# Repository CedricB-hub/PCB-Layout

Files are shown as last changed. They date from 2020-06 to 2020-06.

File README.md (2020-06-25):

# PCB-Layout

New Github repository to host a project sample

Licence Attribution-ShareAlike 3.0 Unported: https://creativecommons.org/licenses/by-sa/3.0/legalcode

The cover page, the block diagram, the schematics design notes and the pcb manufacturing notes were taken from the original design. The schematics library, pcb library, schematics, pcb design and release documentation were made according to what is shown in the course "Learn to design your own boards". (I wanted to repeat the pcb design steps shown by a professional from start to finish to learn pcb design best practices and better estimate the time it takes to develop a pcb with all the documentation for manufacturing)

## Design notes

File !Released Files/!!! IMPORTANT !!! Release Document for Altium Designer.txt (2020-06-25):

Follow this procedure before releasing files. Confirm every action with your initials and date.
IF ANY CHANGES NEEDS TO BE DONE, START THE PROCEDURE FROM BEGINNING!

The procedure needs to be executed in order as defined here. Start from number 1
--------------------------------------------------------------------------------

1) Right Click on the project -> Compile PCB project
I confirm, the project compiles with no errors: 
BC [22-06-2020]

2) Run Design -> Update PCB Document
I confirm, there are no differences between Schematic and PCB: 
BC [22-06-2020]

3) Impedance
I confirm, I have updated and check track width/gap to match required impedance (e.g 55 OHMs): 
NOT APPLICABLE  (two layers, low speed signals)

4) Run Tools -> Polygon Pours -> Rebuild All
I confirm, all polygons have been repoured: 
BC [22-06-2020]

5) Run Tools -> Design Rule Check -> Run Design Rule Check
I confirm, I have checked Design Rule Output File:
BC [22-06-2020]

6) Gerber check
I confirm, I have copied and visually checked gerber files placed in \PCB Manufacturing\Gerber Output\
BC [22-06-2020]

7) Other files
I confirm, I have copied and checked files placed in subdirectories:
BC [22-06-2020]

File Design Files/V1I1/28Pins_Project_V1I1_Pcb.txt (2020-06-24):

Board Information Report
Filename     : C:\Users\cedri\Desktop\FEDEVEL Academy\28 Pins\Design Files\V1I1\28Pins_Project_V1I1_Pcb.PcbDoc
Date         : 22/06/2020
Time         : 15:36:49
Time Elapsed : 00:00:01

General
    Board Size, 68.58mmx53.34mm
    Components on board, 106
count : 2

Routing Information
    Routing completion, 99,15%
    Connections, 236
    Connections routed, 234
    Connections remaining, 2
count : 4

Layer, Arcs, Pads, Vias, Tracks, Texts, Fills, Regions, ComponentBodies
    L1, 2, 221, 0, 913, 0, 0, 14, 0
    L2, 1, 0, 0, 94, 0, 0, 11, 0
    Mechanical 1, 0, 0, 0, 0, 0, 0, 0, 104
    Mechanical Drawing, 5, 0, 0, 149, 22, 0, 0, 0
    Manufacturing Notes, 0, 0, 0, 10, 32, 0, 0, 0
    License, 0, 0, 0, 0, 25, 0, 0, 0
    Board Outline, 0, 0, 0, 5, 0, 0, 0, 0
    ASM Top, 22, 0, 0, 391, 100, 0, 0, 0
    ASM Bot, 0, 0, 0, 0, 0, 0, 0, 0
    Multi-Layer, 0, 102, 105, 0, 0, 0, 1, 0
    Top Paste, 0, 0, 0, 0, 0, 0, 0, 0
    Top Overlay, 3, 0, 0, 423, 235, 0, 0, 0
    Top Solder, 0, 0, 0, 0, 0, 0, 0, 0
    Bottom Solder, 0, 0, 0, 0, 0, 0, 0, 0
    Bottom Overlay, 0, 0, 0, 0, 36, 0, 0, 0
    Bottom Paste, 0, 0, 0, 0, 0, 0, 0, 0
    Drill Guide, 0, 0, 0, 0, 0, 0, 0, 0
    Keep-Out Layer, 0, 0, 0, 0, 0, 0, 0, 0
    Drill Drawing, 0, 0, 0, 0, 0, 0, 0, 0
count : 19

Drill Pairs, Vias
    L1 - L2, 105
count : 1

Layer, Sq.In., Sq.MM., Percent of layer
    L1, 2,041, 1316,752, 36%
    L2, 3,972, 2562,467, 70%
count : 2

Non-Plated Hole Size, Pads, Vias
    3.2mm, 1, 0
count : 1

Plated Hole Size, Pads, Vias
    0mm, 221, 0
    0.3mm, 0, 105
    1mm, 8, 0
    1.1mm, 86, 0
    1.5mm, 2, 0
    3.2mm, 3, 0
count : 6

Non-Plated Slot Size / Length, Pads
count : 0

Plated Slot Size / Length, Pads
    19.685mil / 47.244mil, 2
count : 1

Non-Plated Square Hole Size, Pads
count : 0

Plated Square Hole Size, Pads
count : 0

Top Layer Annular Ring Size, Count
    0mm, 1
    0.3mm, 105
    0.6mm, 16
    0.9mm, 8
    0.9mm, 70
    1.5mm, 2
    2.5mm, 2
    4.2mm, 3
count : 8

Mid Layer Annular Ring Size, Count
    0mm, 1
    0.3mm, 105
    0.6mm, 16
    0.9mm, 8
    0.9mm, 70
    1.1mm, 1
    1.5mm, 1
    2.5mm, 2
    4.2mm, 3
count : 9

Bottom Layer Annular Ring Size, Count
    0mm, 1
    0.3mm, 105
    0.6mm, 16
    0.9mm, 8
    0.9mm, 70
    1.1mm, 1
    1.5mm, 1
    2.5mm, 2
    4.2mm, 3
count : 9

Pad Solder Mask, Count
    0.05mm, 5
    0.06mm, 32
    0.1mm, 282
    1.016mm, 4
count : 4

Pad Paste Mask, Count
    -1.016mm, 4
    0mm, 319
count : 2

Pad Pwr/Gnd Expansion, Count
    0.508mm, 323
count : 1

Pad Relief Conductor Width, Count
    0.254mm, 323
count : 1

Pad Relief Air Gap, Count
    0.254mm, 323
count : 1

Pad Relief Entries, Count
    4, 323
count : 1

Via Solder Mask, Count
    0.1mm, 85
    0.1016mm, 20
count : 2

Via Pwr/Gnd Expansion, Count
    0.508mm, 105
count : 1

Track Width, Count
    0.2mm, 907
    0.254mm, 154
    0.3mm, 619
    0.4mm, 14
    0.6mm, 204
    0.8mm, 61
    1mm, 26
count : 7

Arc Line Width, Count
    0.2mm, 4
    0.254mm, 7
    0.3mm, 3
    0.45mm, 1
    0.5mm, 3
    0.508mm, 7
    0.635mm, 3
    1.016mm, 5
count : 8

Arc Radius, Count
    0.1mm, 9
    0.2mm, 1
    0.2236mm, 2
    0.25mm, 1
    0.254mm, 10
    0.635mm, 1
    1.1833mm, 1
    1.6mm, 5
    1.8448mm, 1
    3.7mm, 1
    4.05mm, 1
count : 11

Arc Degrees, Count
    8, 1
    13, 2
    149, 1
    180, 1
    360, 28
count : 5

Text Height, Count
    0.5mm, 2
    0.6mm, 73
    0.8mm, 5
    1mm, 170
    1.016mm, 7
    1.27mm, 3
    1.524mm, 179
    1.8mm, 1
    2mm, 2
    3mm, 6
    4mm, 2
count : 11

Text Width, Count
    0.1mm, 76
    0.127mm, 4
    0.15mm, 1
    0.1524mm, 18
    0.2mm, 174
    0.25mm, 1
    0.254mm, 167
    0.3mm, 2
    0.5mm, 5
    0.8mm, 2
count : 10

Net Track Width, Count
    0.2mm, 61
    0.4mm, 10
count : 2

Net Via Size, Count
    0.6mm, 71
count : 1

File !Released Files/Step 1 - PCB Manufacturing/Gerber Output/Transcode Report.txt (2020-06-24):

   ---- Transcoding 'C:\Users\cedri\Desktop\FEDEVEL Academy\28 Pins\!Released Files\Step 1 - PCB Manufacturing\Gerber Output\28Pins_Project_V1I1_Pcb.GM2' ----   Mon Jun 22 15:15:35 2020

D88   --> D100
-----------------------------------------------------------------

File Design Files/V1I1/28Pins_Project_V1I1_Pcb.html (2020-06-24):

Altium customize

# Board Information Report

Date: | | 22/06/2020
Time: | | 15:36:49
Elapsed Time: | | 00:00:01
Filename: | | C:\Users\cedri\Desktop\FEDEVEL Academy\28 Pins\Design Files\V1I1\28Pins_Project_V1I1_Pcb.PcbDoc
Units: | | mmmils

## Contents

Contents

Board Specification

General

Routing

Routing Information

Layer Information

Layer Information

Drill Pairs

Copper Area

Copper Area

Board Holes

Non-Plated Hole Size

Plated Hole Size

Board Slots

Non-Plated Slot Size

Plated Slot Size

Board Square Holes

Non-Plated Square Hole Size

Plated Square Hole Size

Other

Top Layer Annular Ring Size

Mid Layer Annular Ring Size

Bottom Layer Annular Ring Size

Pad Solder Mask

Pad Paste Mask

Pad Pwr/Gnd Expansion

Pad Relief Conductor Width

Pad Relief Air Gap

Pad Relief Entries

Via Solder Mask

Via Pwr/Gnd Expansion

Track Width

Arc Line Width

Arc Radius

Arc Degrees

Text Height

Text Width

Net Track Width

Net Via Size

## Board Specification

General
Board Size | 68.58mm x 53.34mm
Components on board | 106

Back to top

## Routing

Routing Information
Routing completion | 99,15%
Connections | 236
Connections routed | 234
Connections remaining | 2

Back to top

## Layer Information

Layer | Arcs | Pads | Vias | Tracks | Texts | Fills | Regions | ComponentBodies
L1 | 2 | 221 | 0 | 913 | 0 | 0 | 14 | 0
L2 | 1 | 0 | 0 | 94 | 0 | 0 | 11 | 0
Mechanical 1 | 0 | 0 | 0 | 0 | 0 | 0 | 0 | 104
Mechanical Drawing | 5 | 0 | 0 | 149 | 22 | 0 | 0 | 0
Manufacturing Notes | 0 | 0 | 0 | 10 | 32 | 0 | 0 | 0
License | 0 | 0 | 0 | 0 | 25 | 0 | 0 | 0
Board Outline | 0 | 0 | 0 | 5 | 0 | 0 | 0 | 0
ASM Top | 22 | 0 | 0 | 391 | 100 | 0 | 0 | 0
ASM Bot | 0 | 0 | 0 | 0 | 0 | 0 | 0 | 0
Multi-Layer | 0 | 102 | 105 | 0 | 0 | 0 | 1 | 0
Top Paste | 0 | 0 | 0 | 0 | 0 | 0 | 0 | 0
Top Overlay | 3 | 0 | 0 | 423 | 235 | 0 | 0 | 0
Top Solder | 0 | 0 | 0 | 0 | 0 | 0 | 0 | 0
Bottom Solder | 0 | 0 | 0 | 0 | 0 | 0 | 0 | 0
Bottom Overlay | 0 | 0 | 0 | 0 | 36 | 0 | 0 | 0
Bottom Paste | 0 | 0 | 0 | 0 | 0 | 0 | 0 | 0
Drill Guide | 0 | 0 | 0 | 0 | 0 | 0 | 0 | 0
Keep-Out Layer | 0 | 0 | 0 | 0 | 0 | 0 | 0 | 0
Drill Drawing | 0 | 0 | 0 | 0 | 0 | 0 | 0 | 0
Total | 33 | 323 | 105 | 1985 | 450 | 0 | 26 | 104

Back to top

Drill Pairs | Vias
L1 - L2 | 105
Total | 105

Back to top

## Copper Area

Layer | Sq.In. | Sq.MM. | Percent of layer
L1 | 2,041 | 1316,752 | 36%
L2 | 3,972 | 2562,467 | 70%
Total | NaN | NaN

Back to top

## Board Holes

Non-Plated Hole Size | Pads | Vias
3.2mm | 1 | 0
Total | 1 | 0

Back to top

Plated Hole Size | Pads | Vias
0mm | 221 | 0
0.3mm | 0 | 105
1mm | 8 | 0
1.1mm | 86 | 0
1.5mm | 2 | 0
3.2mm | 3 | 0
Total | 320 | 105

Back to top

## Board Slots

Non-Plated Slot Size / Length | Pads
Total | 0

Back to top

Plated Slot Size / Length | Pads
19.685mil / 47.244mil | 2
Total | 2

Back to top

## Board Square Holes

Non-Plated Square Hole Size | Pads
Total | 0

Back to top

Plated Square Hole Size | Pads
Total | 0

Back to top

## Other

Top Layer Annular Ring Size | Count
0mm | 1
0.3mm | 105
0.6mm | 16
0.9mm | 8
0.9mm | 70
1.5mm | 2
2.5mm | 2
4.2mm | 3
Total | 207

Back to top

Mid Layer Annular Ring Size | Count
0mm | 1
0.3mm | 105
0.6mm | 16
0.9mm | 8
0.9mm | 70
1.1mm | 1
1.5mm | 1
2.5mm | 2
4.2mm | 3
Total | 207

Back to top

Bottom Layer Annular Ring Size | Count
0mm | 1
0.3mm | 105
0.6mm | 16
0.9mm | 8
0.9mm | 70
1.1mm | 1
1.5mm | 1
2.5mm | 2
4.2mm | 3
Total | 207

Back to top

Pad Solder Mask | Count
0.05mm | 5
0.06mm | 32
0.1mm | 282
1.016mm | 4
Total | 323

Back to top

Pad Paste Mask | Count
-1.016mm | 4
0mm | 319
Total | 323

Back to top

Pad Pwr/Gnd Expansion | Count
0.508mm | 323
Total | 323

Back to top

Pad Relief Conductor Width | Count
0.254mm | 323
Total | 323

Back to top

Pad Relief Air Gap | Count
0.254mm | 323
Total | 323

Back to top

Pad Relief Entries | Count
4 | 323
Total | 323

Back to top

Via Solder Mask | Count
0.1mm | 85
0.1016mm | 20
Total | 105

Back to top

Via Pwr/Gnd Expansion | Count
0.508mm | 105
Total | 105

Back to top

Track Width | Count
0.2mm | 907
0.254mm | 154
0.3mm | 619
0.4mm | 14
0.6mm | 204
0.8mm | 61
1mm | 26
Total | 1985

Back to top

Arc Line Width | Count
0.2mm | 4
0.254mm | 7
0.3mm | 3
0.45mm | 1
0.5mm | 3
0.508mm | 7
0.635mm | 3
1.016mm | 5
Total | 33

Back to top

Arc Radius | Count
0.1mm | 9
0.2mm | 1
0.2236mm | 2
0.25mm | 1
0.254mm | 10
0.635mm | 1
1.1833mm | 1
1.6mm | 5
1.8448mm | 1
3.7mm | 1
4.05mm | 1
Total | 33

Back to top

Arc Degrees | Count
8 | 1
13 | 2
149 | 1
180 | 1
360 | 28
Total | 33

Back to top

Text Height | Count
0.5mm | 2
0.6mm | 73
0.8mm | 5
1mm | 170
1.016mm | 7
1.27mm | 3
1.524mm | 179
1.8mm | 1
2mm | 2
3mm | 6
4mm | 2
Total | 450

Back to top

Text Width | Count
0.1mm | 76
0.127mm | 4
0.15mm | 1
0.1524mm | 18
0.2mm | 174
0.25mm | 1
0.254mm | 167
0.3mm | 2
0.5mm | 5
0.8mm | 2
Total | 450

Back to top

Net Track Width | Count
0.2mm | 61
0.4mm | 10
Total | 71

Back to top

Net Via Size | Count
0.6mm | 71
Total | 71

Back to top

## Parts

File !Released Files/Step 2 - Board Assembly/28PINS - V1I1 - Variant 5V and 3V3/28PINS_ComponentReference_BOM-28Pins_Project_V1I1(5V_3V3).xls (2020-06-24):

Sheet: Part List Report
 | Component reference list |  |  | DEV Board learning project
 |  | Source Data From: | 28Pins_Project_V1I1.PrjPcb |  | Contact: |  | Generated by:
 |  | Project: | 28Pins_Project_V1I1.PrjPcb
 |  | Variant: | 5V/3V3 |  |  |  | FEDEVEL
 | Report Date: | 22/06/2020 | 17:35 |  |  |  | http://www.fedevel.com
 | Print Date: | 2020-06-22 | 17:35:31
# | Designator | Comment | Description | Manufacturer 1 | Manufacturer Part Number 1 | Case/Package | Supplier 1 | Supplier Part Number 1
1 | C1 | 100u / 10V | Cap Aluminum 100uF 10V 20% (5 X 5.4mm) SMD 50mA 1000 hr 85°C T/R | Panasonic | EEE-1AA101WR | Radial | Digi-Key | PCE3867CT-ND
2 | C2 | 100u / 10V | Cap Aluminum 100uF 10V 20% (5 X 5.4mm) SMD 50mA 1000 hr 85°C T/R | Panasonic | EEE-1AA101WR | Radial | Digi-Key | PCE3867CT-ND
3 | C3 | 10u / 16V | TDK - C2012X5R1C106K085AC - SMD Multilayer Ceramic Capacitor, 10 µF, 16 V, 0805 [2012 Metric], ± 10%, X5R, C Series TDK | TDK | C2012X5R1C106K085AC | 805 | Digi-Key | 445-7644-1-ND
4 | C4 | 100n | TDK - C2012X7R1H104K085AA - SMD Multilayer Ceramic Capacitor, 0.1 µF, 50 V, 0805 [2012 Metric], ± 10%, X7R, C Series | TDK | C2012X7R1H104K085AA | 805 | Digi-Key | 445-7534-1-ND
5 | C5 | 100n | TDK - C2012X7R1H104K085AA - SMD Multilayer Ceramic Capacitor, 0.1 µF, 50 V, 0805 [2012 Metric], ± 10%, X7R, C Series | TDK | C2012X7R1H104K085AA | 805 | Digi-Key | 445-7534-1-ND
6 | C6 | 100n | TDK - C2012X7R1H104K085AA - SMD Multilayer Ceramic Capacitor, 0.1 µF, 50 V, 0805 [2012 Metric], ± 10%, X7R, C Series | TDK | C2012X7R1H104K085AA | 805 | Digi-Key | 445-7534-1-ND
7 | C7 | 1u / 25V | TDK - C2012X5R1E105K125AA - SMD Multilayer Ceramic Capacitor, 1 µF, 25 V, 0805 [2012 Metric], ± 10%, X5R, C Series | TDK | C2012X5R1E105K125AA | 805 | Digi-Key | 445-1419-1-ND
8 | C8 | 100n | TDK - C2012X7R1H104K085AA - SMD Multilayer Ceramic Capacitor, 0.1 µF, 50 V, 0805 [2012 Metric], ± 10%, X7R, C Series | TDK | C2012X7R1H104K085AA | 805 | Digi-Key | 445-7534-1-ND
9 | C9 | 18p | CAP CER 18PF 50V C0G/NP0 0805 | KEMET | C0805C180J5GACTU | 805 | Digi-Key | 399-1112-1-ND
10 | C10 | 18p | CAP CER 18PF 50V C0G/NP0 0805 | KEMET | C0805C180J5GACTU | 805 | Digi-Key | 399-1112-1-ND
11 | C11 | 100n | TDK - C2012X7R1H104K085AA - SMD Multilayer Ceramic Capacitor, 0.1 µF, 50 V, 0805 [2012 Metric], ± 10%, X7R, C Series | TDK | C2012X7R1H104K085AA | 805 | Digi-Key | 445-7534-1-ND
12 | C12 | 10u / 16V | TDK - C2012X5R1C106K085AC - SMD Multilayer Ceramic Capacitor, 10 µF, 16 V, 0805 [2012 Metric], ± 10%, X5R, C Series TDK | TDK | C2012X5R1C106K085AC | 805 | Digi-Key | 445-7644-1-ND
13 | C13 | 10u / 16V | TDK - C2012X5R1C106K085AC - SMD Multilayer Ceramic Capacitor, 10 µF, 16 V, 0805 [2012 Metric], ± 10%, X5R, C Series TDK | TDK | C2012X5R1C106K085AC | 805 | Digi-Key | 445-7644-1-ND
14 | C14 | 100n | TDK - C2012X7R1H104K085AA - SMD Multilayer Ceramic Capacitor, 0.1 µF, 50 V, 0805 [2012 Metric], ± 10%, X7R, C Series | TDK | C2012X7R1H104K085AA | 805 | Digi-Key | 445-7534-1-ND
15 | C15 | 100n | TDK - C2012X7R1H104K085AA - SMD Multilayer Ceramic Capacitor, 0.1 µF, 50 V, 0805 [2012 Metric], ± 10%, X7R, C Series | TDK | C2012X7R1H104K085AA | 805 | Digi-Key | 445-7534-1-ND
16 | C16 | 100n | TDK - C2012X7R1H104K085AA - SMD Multilayer Ceramic Capacitor, 0.1 µF, 50 V, 0805 [2012 Metric], ± 10%, X7R, C Series | TDK | C2012X7R1H104K085AA | 805 | Digi-Key | 445-7534-1-ND
17 | C17 | 100n | TDK - C2012X7R1H104K085AA - SMD Multilayer Ceramic Capacitor, 0.1 µF, 50 V, 0805 [2012 Metric], ± 10%, X7R, C Series | TDK | C2012X7R1H104K085AA | 805 | Digi-Key | 445-7534-1-ND
18 | C19 | 10u / 16V | TDK - C2012X5R1C106K085AC - SMD Multilayer Ceramic Capacitor, 10 µF, 16 V, 0805 [2012 Metric], ± 10%, X5R, C Series TDK | TDK | C2012X5R1C106K085AC | 805 | Digi-Key | 445-7644-1-ND
19 | C20 | 100n | TDK - C2012X7R1H104K085AA - SMD Multilayer Ceramic Capacitor, 0.1 µF, 50 V, 0805 [2012 Metric], ± 10%, X7R, C Series | TDK | C2012X7R1H104K085AA | 805 | Digi-Key | 445-7534-1-ND
20 | C21 | 10u / 16V | TDK - C2012X5R1C106K085AC - SMD Multilayer Ceramic Capacitor, 10 µF, 16 V, 0805 [2012 Metric], ± 10%, X5R, C Series TDK | TDK | C2012X5R1C106K085AC | 805 | Digi-Key | 445-7644-1-ND
21 | C22 | 10u / 16V | TDK - C2012X5R1C106K085AC - SMD Multilayer Ceramic Capacitor, 10 µF, 16 V, 0805 [2012 Metric], ± 10%, X5R, C Series TDK | TDK | C2012X5R1C106K085AC | 805 | Digi-Key | 445-7644-1-ND
22 | C23 | 100n | TDK - C2012X7R1H104K085AA - SMD Multilayer Ceramic Capacitor, 0.1 µF, 50 V, 0805 [2012 Metric], ± 10%, X7R, C Series | TDK | C2012X7R1H104K085AA | 805 | Digi-Key | 445-7534-1-ND
23 | C24 | 100n | TDK - C2012X7R1H104K085AA - SMD Multilayer Ceramic Capacitor, 0.1 µF, 50 V, 0805 [2012 Metric], ± 10%, X7R, C Series | TDK | C2012X7R1H104K085AA | 805 | Digi-Key | 445-7534-1-ND
24 | C25 | 18p | CAP CER 18PF 50V C0G/NP0 0805 | KEMET | C0805C180J5GACTU | 805 | Digi-Key | 399-1112-1-ND
25 | C26 | 100n | TDK - C2012X7R1H104K085AA - SMD Multilayer Ceramic Capacitor, 0.1 µF, 50 V, 0805 [2012 Metric], ± 10%, X7R, C Series | TDK | C2012X7R1H104K085AA | 805 | Digi-Key | 445-7534-1-ND
26 | C27 | 18p | CAP CER 18PF 50V C0G/NP0 0805 | KEMET | C0805C180J5GACTU | 805 | Digi-Key | 399-1112-1-ND
27 | C28 | 100n | TDK - C2012X7R1H104K085AA - SMD Multilayer Ceramic Capacitor, 0.1 µF, 50 V, 0805 [2012 Metric], ± 10%, X7R, C Series | TDK | C2012X7R1H104K085AA | 805 | Digi-Key | 445-7534-1-ND
28 | C29 | 100n | TDK - C2012X7R1H104K085AA - SMD Multilayer Ceramic Capacitor, 0.1 µF, 50 V, 0805 [2012 Metric], ± 10%, X7R, C Series | TDK | C2012X7R1H104K085AA | 805 | Digi-Key | 445-7534-1-ND
29 | C30 | 100n | TDK - C2012X7R1H104K085AA - SMD Multilayer Ceramic Capacitor, 0.1 µF, 50 V, 0805 [2012 Metric], ± 10%, X7R, C Series | TDK | C2012X7R1H104K085AA | 805 | Digi-Key | 445-7534-1-ND
30 | C31 | 100n | TDK - C2012X7R1H104K085AA - SMD Multilayer Ceramic Capacitor, 0.1 µF, 50 V, 0805 [2012 Metric], ± 10%, X7R, C Series | TDK | C2012X7R1H104K085AA | 805 | Digi-Key | 445-7534-1-ND
31 | C32 | 100n | TDK - C2012X7R1H104K085AA - SMD Multilayer Ceramic Capacitor, 0.1 µF, 50 V, 0805 [2012 Metric], ± 10%, X7R, C Series | TDK | C2012X7R1H104K085AA | 805 | Digi-Key | 445-7534-1-ND
32 | C33 | 100n | TDK - C2012X7R1H104K085AA - SMD Multilayer Ceramic Capacitor, 0.1 µF, 50 V, 0805 [2012 Metric], ± 10%, X7R, C Series | TDK | C2012X7R1H104K085AA | 805 | Digi-Key | 445-7534-1-ND
33 | C34 | 10u / 16V | TDK - C2012X5R1C106K085AC - SMD Multilayer Ceramic Capacitor, 10 µF, 16 V, 0805 [2012 Metric], ± 10%, X5R, C Series TDK | TDK | C2012X5R1C106K085AC | 805 | Digi-Key | 445-7644-1-ND
34 | D1 | Green | LED Uni-Color Green 572nm 2-Pin Chip 0603(1608Metric) T/R | Osram Opto | LGL29K-G2J1-24-Z | 603 | Digi-Key | 475-2709-1-ND
35 | D2 | Green | LED Uni-Color Green 572nm 2-Pin Chip 0603(1608Metric) T/R | Osram Opto | LGL29K-G2J1-24-Z | 603 | Digi-Key | 475-2709-1-ND
36 | D3 | Orange | OSRAM - LO L29K-H2K1-24-Z - SMARTLED 0603 ORANGE | Osram Opto | LOL29K-H2K1-24-Z | 603 | Digi-Key | 475-2740-1-ND
37 | D4 | Orange | OSRAM - LO L29K-H2K1-24-Z - SMARTLED 0603 ORANGE | Osram Opto | LOL29K-H2K1-24-Z | 603 | Digi-Key | 475-2740-1-ND
38 | D5 | BAT54HT1G | Small Signal Schottky Diode, Single, 30 V, 200 mA, 800 mV, 600 mA, 150 C ;RoHS Compliant: Yes | ON Semiconductor / Fairchild | BAT54HT1G |  | Digi-Key | BAT54HT1GOSCT-ND
39 | D6 | BAT54HT1G | Small Signal Schottky Diode, Single, 30 V, 200 mA, 800 mV, 600 mA, 150 C ;RoHS Compliant: Yes | ON Semiconductor / Fairchild | BAT54HT1G |  | Digi-Key | BAT54HT1GOSCT-ND
40 | FB1 | MPZ2012S601AT000 | FERRITE BEAD 600 OHM 0805 1LN | TDK | MPZ2012S601AT000 | 805 | Digi-Key | 445-2206-1-ND
41 | FB2 | MPZ2012S601AT000 | FERRITE BEAD 600 OHM 0805 1LN | TDK | MPZ2012S601AT000 | 805 | Digi-Key | 445-2206-1-ND
42 | FB3 | MPZ2012S601AT000 | FERRITE BEAD 600 OHM 0805 1LN | TDK | MPZ2012S601AT000 | 805 | Digi-Key | 445-2206-1-ND
43 | J1 | HDR FEMALE 1x8 2.54 | 2.54mm (0.1") Pitch SIL Vertical PC Tail Socket Assembly, selective gold + tin, 8 contacts | Harwin | M20-7820842 | SIL | Digi-Key | 952-1823-ND
44 | J2 | HDR Female 1x6 2.54 | 06-WAY SIL VERT SOCKET L/FREE | Harwin | M20-7820646 | SIL | Digi-Key | 952-1809-ND
45 | J3 | HDR FEMALE 1x8 2.54 | 2.54mm (0.1") Pitch SIL Vertical PC Tail Socket Assembly, selective gold + tin, 8 contacts | Harwin | M20-7820842 | SIL | Digi-Key | 952-1823-ND
46 | J4 | HDR Female 1x10 2.54 | HARWIN - M20-7821046 - Board-To-Board Connector, M20 Series, Through Hole, Receptacle, 10, 2.54 mm, Tin Plated Contacts | Harwin | M20-7821046 | SIL | Digi-Key | 952-1847-ND
47 | J5 | HDR 2x3 2.54 | CONN HEADER 6POS .100 STR 30AU | Amphenol ICC / FCI | 67997-106HLF |  | Digi-Key | 609-3393-ND
48 | J6 | HDR 2x3 2.54 | CONN HEADER 6POS .100 STR 30AU | Amphenol ICC / FCI | 67997-106HLF |  | Digi-Key | 609-3393-ND
49 | J7 | 10118193-0001LF | CONN USB MICRO B RECPT SMT R/A | AMPHENOL ICC (FCI) | 10118193-0001LF |  | Digi-Key | 609-4616-1-ND
50 | JP1 | HDR 1x3 | Conn Unshrouded Header HDR 3 POS 2.54mm Solder ST Thru-Hole Bulk | Amphenol ICC | 68000-103HLF |  | Digi-Key | 609-3461-ND
51 | JP3 | HDR 1x4 | CONN HEADER VERT 4POS 2.54MM | Amphenol FCI | 68001-204HLF |  | Digi-Key | 609-3402-ND
52 | JP4 | HDR 1x3 | Conn Unshrouded Header HDR 3 POS 2.54mm Solder ST Thru-Hole Bulk | Amphenol ICC | 68000-103HLF |  | Digi-Key | 609-3461-ND
53 | L1 | 2u2 / 2A | FIXED IND 2.2UH 2A 80 MOHM SMD | KEMET | L1210R2R2MDWIT | 1210 | Digi-Key | 399-9598-1-ND
54 | LINK1 | LINK | CONN JUMPER SHORTING .100" GOLD | Sullins | QPC02SXGN-RC | 100 | Digi-Key | S9337-ND
55 | LINK2 | LINK | CONN JUMPER SHORTING .100" GOLD | Sullins | QPC02SXGN-RC | 100 | Digi-Key | S9337-ND
56 | LINK3 | LINK | CONN JUMPER SHORTING .100" GOLD | Sullins | QPC02SXGN-RC | 100 | Digi-Key | S9337-ND
57 | R1 | 100K | YAGEO RC0805FR-07100KL RES, THICK FILM, 100K, 1%, 0.125W, 0805, REEL | Yageo | RC0805FR-07100KL | 805 | Digi-Key | 311-100KCRCT-ND
58 | R2 | 560R | Surface Mount Thick Film Resistor, RC Series, 560 ohm, 125 mW, - 1%, 150 V, 0805 [2012 Metric] | Yageo | RC0805FR-07560RL | 805 | Digi-Key | 311-560CRCT-ND
59 | R3 | 560R | Surface Mount Thick Film Resistor, RC Series, 560 ohm, 125 mW, - 1%, 150 V, 0805 [2012 Metric] | Yageo | RC0805FR-07560RL | 805 | Digi-Key | 311-560CRCT-ND
60 | R4 | 10K | RES SMD 10K OHM 1% 1/8W 0805 | Yageo | RC0805FR-0710KL | 805 | Digi-Key | 311-10.0KCRCT-ND
61 | R5 | 22R | RES SMD 22 OHM 1% 1/8W 0805 | Yageo | RC0805FR-0722RL | 805 | Digi-Key | 311-22.0CRCT-ND
62 | R6 | 22R | RES SMD 22 OHM 1% 1/8W 0805 | Yageo | RC0805FR-0722RL | 805 | Digi-Key | 311-22.0CRCT-ND
63 | R7 | 22R | RES SMD 22 OHM 1% 1/8W 0805 | Yageo | RC0805FR-0722RL | 805 | Digi-Key | 311-22.0CRCT-ND
64 | R8 | 0R | Surface Mount Thick Film Resistor, RC Series, 125 mW, - 5%, 150 V, 0805 [2012 Metric] | Yageo | RC0805JR-070RL | 805 | Digi-Key | 311-0.0ARCT-ND
65 | R9 | 1M | RES SMD 1M OHM 1% 1/8W 0805 | Yageo | RC0805FR-071ML | 805 | Digi-Key | 311-1.00MCRCT-ND
66 | R10 | 1K | RESISTOR, 0805 1K 1%, FULL REEL; Product Range:YAGEO - RC Series; Resistance:1kohm; Power Rating:125mW; Resistance Tolerance:± 1%; Resistor Case Style:0805 [2012 Metric]; Resistor Element Material:Thick Film; Temperature Coefficient:± 250ppm/°C; Voltage Rating:150V; Packaging:Tape & Reel; MSL:-; SVHC:No SVHC (16-Dec-2013); External Depth:0.55mm; External Length / Height:2mm; External Width:1.25mm; No. of Pins:2; Operating Temperature Max:155°C; Operating Temperature Min:-55°C; Operating Temperature Range:-55°C to +155°C; Reel Quantity:5000; Resistor Mounting:SMD; Series:RC12H; Temperature Coef | Yageo | RC0805FR-071KL | 805 | Digi-Key | 311-1.00KCRCT-ND
67 | R11 | 1K | RESISTOR, 0805 1K 1%, FULL REEL; Product Range:YAGEO - RC Series; Resistance:1kohm; Power Rating:125mW; Resistance Tolerance:± 1%; Resistor Case Style:0805 [2012 Metric]; Resistor Element Material:Thick Film; Temperature Coefficient:± 250ppm/°C; Voltage Rating:150V; Packaging:Tape & Reel; MSL:-; SVHC:No SVHC (16-Dec-2013); External Depth:0.55mm; External Length / Height:2mm; External Width:1.25mm; No. of Pins:2; Operating Temperature Max:155°C; Operating Temperature Min:-55°C; Operating Temperature Range:-55°C to +155°C; Reel Quantity:5000; Resistor Mounting:SMD; Series:RC12H; Temperature Coef | Yageo | RC0805FR-071KL | 805 | Digi-Key | 311-1.00KCRCT-ND
68 | R12 | 1K | RESISTOR, 0805 1K 1%, FULL REEL; Product Range:YAGEO - RC Series; Resistance:1kohm; Power Rating:125mW; Resistance Tolerance:± 1%; Resistor Case Style:0805 [2012 Metric]; Resistor Element Material:Thick Film; Temperature Coefficient:± 250ppm/°C; Voltage Rating:150V; Packaging:Tape & Reel; MSL:-; SVHC:No SVHC (16-Dec-2013); External Depth:0.55mm; External Length / Height:2mm; External Width:1.25mm; No. of Pins:2; Operating Temperature Max:155°C; Operating Temperature Min:-55°C; Operating Temperature Range:-55°C to +155°C; Reel Quantity:5000; Resistor Mounting:SMD; Series:RC12H; Temperature Coef | Yageo | RC0805FR-071KL | 805 | Digi-Key | 311-1.00KCRCT-ND
69 | R13 | 22R | RES SMD 22 OHM 1% 1/8W 0805 | Yageo | RC0805FR-0722RL | 805 | Digi-Key | 311-22.0CRCT-ND
70 | R14 | 10K | RES SMD 10K OHM 1% 1/8W 0805 | Yageo | RC0805FR-0710KL | 805 | Digi-Key | 311-10.0KCRCT-ND
71 | R15 | 560R | Surface Mount Thick Film Resistor, RC Series, 560 ohm, 125 mW, - 1%, 150 V, 0805 [2012 Metric] | Yageo | RC0805FR-07560RL | 805 | Digi-Key | 311-560CRCT-ND
72 | R16 | 1M | RES SMD 1M OHM 1% 1/8W 0805 | Yageo | RC0805FR-071ML | 805 | Digi-Key | 311-1.00MCRCT-ND
73 | R17 | 560R | Surface Mount Thick Film Resistor, RC Series, 560 ohm, 125 mW, - 1%, 150 V, 0805 [2012 Metric] | Yageo | RC0805FR-07560RL | 805 | Digi-Key | 311-560CRCT-ND
74 | R18 | 10K | RES SMD 10K OHM 1% 1/8W 0805 | Yageo | RC0805FR-0710KL | 805 | Digi-Key | 311-10.0KCRCT-ND
75 | R19 | 10K | RES SMD 10K OHM 1% 1/8W 0805 | Yageo | RC0805FR-0710KL | 805 | Digi-Key | 311-10.0KCRCT-ND
76 | R20 | 10K | RES SMD 10K OHM 1% 1/8W 0805 | Yageo | RC0805FR-0710KL | 805 | Digi-Key | 311-10.0KCRCT-ND
77 | R21 | 10K | RES SMD 10K OHM 1% 1/8W 0805 | Yageo | RC0805FR-0710KL | 805 | Digi-Key | 311-10.0KCRCT-ND
78 | R22 | 560R | Surface Mount Thick Film Resistor, RC Series, 560 ohm, 125 mW, - 1%, 150 V, 0805 [2012 Metric] | Yageo | RC0805FR-07560RL | 805 | Digi-Key | 311-560CRCT-ND
79 | R23 | 22R | RES SMD 22 OHM 1% 1/8W 0805 | Yageo | RC0805FR-0722RL | 805 | Digi-Key | 311-22.0CRCT-ND
80 | R24 | 22R | RES SMD 22 OHM 1% 1/8W 0805 | Yageo | RC0805FR-0722RL | 805 | Digi-Key | 311-22.0CRCT-ND
81 | R25 | 22R | RES SMD 22 OHM 1% 1/8W 0805 | Yageo | RC0805FR-0722RL | 805 | Digi-Key | 311-22.0CRCT-ND
82 | SCKT FOR U1 | 28-DIP Socket | CONN IC DIP SOCKET 28POS TIN | 3M | 7010501790 |  | Digi-Key | 3M5480-ND
83 | SW1 | 1825910-6 | SWITCH TACTILE SPST-NO 0.05A 24V | TE Connectivity | FSM4JH |  | Digi-Key | 450-1650-ND
84 | SW2 | 1825910-6 | SWITCH TACTILE SPST-NO 0.05A 24V | TE Connectivity | FSM4JH |  | Digi-Key | 450-1650-ND
85 | U1 | ATMEGA328P-PU | ATMEGA328P-PU; 8 bit Microcontroller AVR 20MHz 1; 32kb Flash; 2kb RAM; I2C SPI 2 | Microchip / Atmel | ATMEGA328P-PU |  | Digi-Key | ATMEGA328P-PU-ND
86 | U2 | ATMEGA16U2-AU | ATmega Series 16 KB Flash 512 B RAM 16 MHz 8-Bit Microcontroller - TQFP-32 | Microchip / Atmel | ATMEGA16U2-AU | TQFP | Digi-Key | ATMEGA16U2-AU-ND
87 | U3 | TL1963A-33DCQR | IC REG LINEAR 3.3V 1.5A SOT223-6 | Texas Instruments | TL1963A-33DCQR | SOT-223 | Digi-Key | 296-24534-1-ND
88 | U4 | SN74AHC1G09DBVR | TEXAS INSTRUMENTS - SN74AHC1G09DBVR - AND Gate, 74AHC1G09, 2 Input, 2 V to 5.5 V, SOT-23-5 | Texas Instruments | SN74AHC1G09DBVR | SOT-23 | Digi-Key | 296-29202-1-ND
89 | U5 | SN74AHC1G09DBVR | TEXAS INSTRUMENTS - SN74AHC1G09DBVR - AND Gate, 74AHC1G09, 2 Input, 2 V to 5.5 V, SOT-23-5 | Texas Instruments | SN74AHC1G09DBVR | SOT-23 | Digi-Key | 296-29202-1-ND
90 | U6 | SN74AHC1G09DBVR | TEXAS INSTRUMENTS - SN74AHC1G09DBVR - AND Gate, 74AHC1G09, 2 Input, 2 V to 5.5 V, SOT-23-5 | Texas Instruments | SN74AHC1G09DBVR | SOT-23 | Digi-Key | 296-29202-1-ND
91 | U7 | SN74AHC1G09DBVR | TEXAS INSTRUMENTS - SN74AHC1G09DBVR - AND Gate, 74AHC1G09, 2 Input, 2 V to 5.5 V, SOT-23-5 | Texas Instruments | SN74AHC1G09DBVR | SOT-23 | Digi-Key | 296-29202-1-ND
92 | Y1 | ABM7-10.000MHZ-D2Y-T | CRYSTAL 10.0000MHZ 18PF SMD | Abracon | ABM7-10.000MHZ-D2Y-T | SMD/SMT | Digi-Key | 535-9833-1-ND
93 | Y2 | ABM7-8.000MHZ-D2Y-T | ABRACON - ABM7-8.000MHZ-D2Y-T - Crystal, Miniature, 8 MHz, SMD, 6mm x 3.5mm, 30 ppm, 18 pF, 20 ppm, ABM7 Series | Abracon | ABM7-8.000MHZ-D2Y-T | CSMD | Digi-Key | 535-9831-1-ND
94 | Z1 | CG0603MLC-05E | VARISTOR 0603 | Bourns | CG0603MLC-05E | 603 | Digi-Key | CG0603MLC-05ECT-ND
95 | Z2 | CG0603MLC-05E | VARISTOR 0603 | Bourns | CG0603MLC-05E | 603 | Digi-Key | CG0603MLC-05ECT-ND
Approved |  |  |  | Notes

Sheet: Project Information
Project Full Path | C:\Users\cedri\Desktop\FEDEVEL Academy\28 Pins\Design Files\V1I1\28Pins_Project_V1I1.PrjPcb
Project Filename | 28Pins_Project_V1I1.PrjPcb
Variant Name | 5V/3V3
Data-Source Filename | 28Pins_Project_V1I1.PrjPcb
Data-Source Full Path | C:\Users\cedri\Desktop\FEDEVEL Academy\28 Pins\Design Files\V1I1\28Pins_Project_V1I1.PrjPcb
Title | 28Pins_Project_V1I1.PrjPcb
Total Quantity | 95
Report Time | 17:35
Report Date | 22/06/2020
Report Date & Tine | 22/06/2020 17:35
Output Name | 28PINS_ComponentReference_BOM
Output Type | BOM_PartType
Output Generator Name | BOM
Output Generator Description | Bill of Materials

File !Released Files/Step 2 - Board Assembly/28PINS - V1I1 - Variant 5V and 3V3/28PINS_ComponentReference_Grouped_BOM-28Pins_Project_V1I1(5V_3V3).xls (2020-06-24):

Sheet: Part List Report
 | Component reference list (grouped) |  |  |  | DEV Board learning project
 | Source Data From: |  | 28Pins_Project_V1I1.PrjPcb |  |  | Contact: |  | Generated by:
 | Project: |  | 28Pins_Project_V1I1.PrjPcb
 | Variant: |  | 5V/3V3 |  |  |  |  | FEDEVEL
 | Report Date: |  | 22/06/2020 | 17:46 |  |  |  | http://www.fedevel.com
 | Print Date: |  | 2020-06-22 | 17:46:30
# | Designator | Quantity | Comment | Description | Manufacturer 1 | Manufacturer Part Number 1 | Case/Package | Supplier 1 | Supplier Part Number 1
1 | C1, C2 | 2 | 100u / 10V | Cap Aluminum 100uF 10V 20% (5 X 5.4mm) SMD 50mA 1000 hr 85°C T/R | Panasonic | EEE-1AA101WR | Radial | Digi-Key | PCE3867CT-ND
2 | C3, C12, C13, C19, C21, C22, C34 | 7 | 10u / 16V | TDK - C2012X5R1C106K085AC - SMD Multilayer Ceramic Capacitor, 10 µF, 16 V, 0805 [2012 Metric], ± 10%, X5R, C Series TDK | TDK | C2012X5R1C106K085AC | 805 | Digi-Key | 445-7644-1-ND
3 | C4, C5, C6, C8, C11, C14, C15, C16, C17, C20, C23, C24, C26, C28, C29, C30, C31, C32, C33 | 19 | 100n | TDK - C2012X7R1H104K085AA - SMD Multilayer Ceramic Capacitor, 0.1 µF, 50 V, 0805 [2012 Metric], ± 10%, X7R, C Series | TDK | C2012X7R1H104K085AA | 805 | Digi-Key | 445-7534-1-ND
4 | C7 | 1 | 1u / 25V | TDK - C2012X5R1E105K125AA - SMD Multilayer Ceramic Capacitor, 1 µF, 25 V, 0805 [2012 Metric], ± 10%, X5R, C Series | TDK | C2012X5R1E105K125AA | 805 | Digi-Key | 445-1419-1-ND
5 | C9, C10, C25, C27 | 4 | 18p | CAP CER 18PF 50V C0G/NP0 0805 | KEMET | C0805C180J5GACTU | 805 | Digi-Key | 399-1112-1-ND
6 | D1, D2 | 2 | Green | LED Uni-Color Green 572nm 2-Pin Chip 0603(1608Metric) T/R | Osram Opto | LGL29K-G2J1-24-Z | 603 | Digi-Key | 475-2709-1-ND
7 | D3, D4 | 2 | Orange | OSRAM - LO L29K-H2K1-24-Z - SMARTLED 0603 ORANGE | Osram Opto | LOL29K-H2K1-24-Z | 603 | Digi-Key | 475-2740-1-ND
8 | D5, D6 | 2 | BAT54HT1G | Small Signal Schottky Diode, Single, 30 V, 200 mA, 800 mV, 600 mA, 150 C ;RoHS Compliant: Yes | ON Semiconductor / Fairchild | BAT54HT1G |  | Digi-Key | BAT54HT1GOSCT-ND
9 | FB1, FB2, FB3 | 3 | MPZ2012S601AT000 | FERRITE BEAD 600 OHM 0805 1LN | TDK | MPZ2012S601AT000 | 805 | Digi-Key | 445-2206-1-ND
10 | J1, J3 | 2 | HDR FEMALE 1x8 2.54 | 2.54mm (0.1") Pitch SIL Vertical PC Tail Socket Assembly, selective gold + tin, 8 contacts | Harwin | M20-7820842 | SIL | Digi-Key | 952-1823-ND
11 | J2 | 1 | HDR Female 1x6 2.54 | 06-WAY SIL VERT SOCKET L/FREE | Harwin | M20-7820646 | SIL | Digi-Key | 952-1809-ND
12 | J4 | 1 | HDR Female 1x10 2.54 | HARWIN - M20-7821046 - Board-To-Board Connector, M20 Series, Through Hole, Receptacle, 10, 2.54 mm, Tin Plated Contacts | Harwin | M20-7821046 | SIL | Digi-Key | 952-1847-ND
13 | J5, J6 | 2 | HDR 2x3 2.54 | CONN HEADER 6POS .100 STR 30AU | Amphenol ICC / FCI | 67997-106HLF |  | Digi-Key | 609-3393-ND
14 | J7 | 1 | 10118193-0001LF | CONN USB MICRO B RECPT SMT R/A | AMPHENOL ICC (FCI) | 10118193-0001LF |  | Digi-Key | 609-4616-1-ND
15 | JP1, JP4 | 2 | HDR 1x3 | Conn Unshrouded Header HDR 3 POS 2.54mm Solder ST Thru-Hole Bulk | Amphenol ICC | 68000-103HLF |  | Digi-Key | 609-3461-ND
16 | JP3 | 1 | HDR 1x4 | CONN HEADER VERT 4POS 2.54MM | Amphenol FCI | 68001-204HLF |  | Digi-Key | 609-3402-ND
17 | L1 | 1 | 2u2 / 2A | FIXED IND 2.2UH 2A 80 MOHM SMD | KEMET | L1210R2R2MDWIT | 1210 | Digi-Key | 399-9598-1-ND
18 | LINK1, LINK2, LINK3 | 3 | LINK | CONN JUMPER SHORTING .100" GOLD | Sullins | QPC02SXGN-RC | 100 | Digi-Key | S9337-ND
19 | R1 | 1 | 100K | YAGEO RC0805FR-07100KL RES, THICK FILM, 100K, 1%, 0.125W, 0805, REEL | Yageo | RC0805FR-07100KL | 805 | Digi-Key | 311-100KCRCT-ND
20 | R2, R3, R15, R17, R22 | 5 | 560R | Surface Mount Thick Film Resistor, RC Series, 560 ohm, 125 mW, - 1%, 150 V, 0805 [2012 Metric] | Yageo | RC0805FR-07560RL | 805 | Digi-Key | 311-560CRCT-ND
21 | R4, R14, R18, R19, R20, R21 | 6 | 10K | RES SMD 10K OHM 1% 1/8W 0805 | Yageo | RC0805FR-0710KL | 805 | Digi-Key | 311-10.0KCRCT-ND
22 | R5, R6, R7, R13, R23, R24, R25 | 7 | 22R | RES SMD 22 OHM 1% 1/8W 0805 | Yageo | RC0805FR-0722RL | 805 | Digi-Key | 311-22.0CRCT-ND
23 | R8 | 1 | 0R | Surface Mount Thick Film Resistor, RC Series, 125 mW, - 5%, 150 V, 0805 [2012 Metric] | Yageo | RC0805JR-070RL | 805 | Digi-Key | 311-0.0ARCT-ND
24 | R9, R16 | 2 | 1M | RES SMD 1M OHM 1% 1/8W 0805 | Yageo | RC0805FR-071ML | 805 | Digi-Key | 311-1.00MCRCT-ND
25 | R10, R11, R12 | 3 | 1K | RESISTOR, 0805 1K 1%, FULL REEL; Product Range:YAGEO - RC Series; Resistance:1kohm; Power Rating:125mW; Resistance Tolerance:± 1%; Resistor Case Style:0805 [2012 Metric]; Resistor Element Material:Thick Film; Temperature Coefficient:± 250ppm/°C; Voltage Rating:150V; Packaging:Tape & Reel; MSL:-; SVHC:No SVHC (16-Dec-2013); External Depth:0.55mm; External Length / Height:2mm; External Width:1.25mm; No. of Pins:2; Operating Temperature Max:155°C; Operating Temperature Min:-55°C; Operating Temperature Range:-55°C to +155°C; Reel Quantity:5000; Resistor Mounting:SMD; Series:RC12H; Temperature Coef | Yageo | RC0805FR-071KL | 805 | Digi-Key | 311-1.00KCRCT-ND
26 | SCKT FOR U1 | 1 | 28-DIP Socket | CONN IC DIP SOCKET 28POS TIN | 3M | 7010501790 |  | Digi-Key | 3M5480-ND
27 | SW1, SW2 | 2 | 1825910-6 | SWITCH TACTILE SPST-NO 0.05A 24V | TE Connectivity | FSM4JH |  | Digi-Key | 450-1650-ND
28 | U1 | 1 | ATMEGA328P-PU | ATMEGA328P-PU; 8 bit Microcontroller AVR 20MHz 1; 32kb Flash; 2kb RAM; I2C SPI 2 | Microchip / Atmel | ATMEGA328P-PU |  | Digi-Key | ATMEGA328P-PU-ND
29 | U2 | 1 | ATMEGA16U2-AU | ATmega Series 16 KB Flash 512 B RAM 16 MHz 8-Bit Microcontroller - TQFP-32 | Microchip / Atmel | ATMEGA16U2-AU | TQFP | Digi-Key | ATMEGA16U2-AU-ND
30 | U3 | 1 | TL1963A-33DCQR | IC REG LINEAR 3.3V 1.5A SOT223-6 | Texas Instruments | TL1963A-33DCQR | SOT-223 | Digi-Key | 296-24534-1-ND
31 | U4, U5, U6, U7 | 4 | SN74AHC1G09DBVR | TEXAS INSTRUMENTS - SN74AHC1G09DBVR - AND Gate, 74AHC1G09, 2 Input, 2 V to 5.5 V, SOT-23-5 | Texas Instruments | SN74AHC1G09DBVR | SOT-23 | Digi-Key | 296-29202-1-ND
32 | Y1 | 1 | ABM7-10.000MHZ-D2Y-T | CRYSTAL 10.0000MHZ 18PF SMD | Abracon | ABM7-10.000MHZ-D2Y-T | SMD/SMT | Digi-Key | 535-9833-1-ND
33 | Y2 | 1 | ABM7-8.000MHZ-D2Y-T | ABRACON - ABM7-8.000MHZ-D2Y-T - Crystal, Miniature, 8 MHz, SMD, 6mm x 3.5mm, 30 ppm, 18 pF, 20 ppm, ABM7 Series | Abracon | ABM7-8.000MHZ-D2Y-T | CSMD | Digi-Key | 535-9831-1-ND
34 | Z1, Z2 | 2 | CG0603MLC-05E | VARISTOR 0603 | Bourns | CG0603MLC-05E | 603 | Digi-Key | CG0603MLC-05ECT-ND
Approved |  |  |  |  | Notes

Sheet: Project Information
Project Full Path | C:\Users\cedri\Desktop\FEDEVEL Academy\28 Pins\Design Files\V1I1\28Pins_Project_V1I1.PrjPcb
Project Filename | 28Pins_Project_V1I1.PrjPcb
Variant Name | 5V/3V3
Data-Source Filename | 28Pins_Project_V1I1.PrjPcb
Data-Source Full Path | C:\Users\cedri\Desktop\FEDEVEL Academy\28 Pins\Design Files\V1I1\28Pins_Project_V1I1.PrjPcb
Title | 28Pins_Project_V1I1.PrjPcb
Total Quantity | 95
Report Time | 17:46
Report Date | 22/06/2020
Report Date & Tine | 22/06/2020 17:46
Output Name | 28PINS_ComponentReference_Grouped_BOM
Output Type | BOM_PartType
Output Generator Name | BOM
Output Generator Description | Bill of Materials

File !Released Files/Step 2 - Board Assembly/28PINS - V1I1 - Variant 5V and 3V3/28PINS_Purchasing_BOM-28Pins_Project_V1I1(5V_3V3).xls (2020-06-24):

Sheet: Part List Report
 | Component list |  |  | 28PINS_Purchasing_BOM for Variant [5V/3V3] of Project [28Pins_Project_V1I1.PrjPcb] (No PCB Document Selected)
 | Source Data From: | 28Pins_Project_V1I1.PrjPcb |  |  | Contact: |  |  |  | Generated by:
 | Project: | 28Pins_Project_V1I1.PrjPcb
 | Variant: | 5V/3V3 |  |  |  |  |  |  | FEDEVEL
 | Report Date: | 22/06/2020 | 17:50 |  |  |  |  |  | http://www.fedevel.com
 | Print Date: | 2020-06-22 | 17:51:09
# | Category | Manufacturer 1 | Manufacturer Part Number 1 | Case/Package | Description | Quantity | Supplier 1 | Supplier Part Number 1 | Supplier Order Qty 1 | Supplier Stock 1 | Supplier Unit Price 1 | Supplier Subtotal 1 | Supplier Currency 1
1 | Aluminum Electrolytic Capacitors | Panasonic | EEE-1AA101WR | Radial | Cap Aluminum 100uF 10V 20% (5 X 5.4mm) SMD 50mA 1000 hr 85°C T/R | 2 | Digi-Key | PCE3867CT-ND | 2 | 50723 | 0.32 | 0.64 | USD
2 | Ceramic Capacitors | TDK | C2012X5R1C106K085AC | 805 | TDK - C2012X5R1C106K085AC - SMD Multilayer Ceramic Capacitor, 10 µF, 16 V, 0805 [2012 Metric], ± 10%, X5R, C Series TDK | 7 | Digi-Key | 445-7644-1-ND | 7 | 1441126 | 0.25 | 1.75 | USD
3 | Ceramic Capacitors | TDK | C2012X7R1H104K085AA | 805 | TDK - C2012X7R1H104K085AA - SMD Multilayer Ceramic Capacitor, 0.1 µF, 50 V, 0805 [2012 Metric], ± 10%, X7R, C Series | 19 | Digi-Key | 445-7534-1-ND | 19 | 228643 | 0.12 | 2.26 | USD
4 | Ceramic Capacitors | TDK | C2012X5R1E105K125AA | 805 | TDK - C2012X5R1E105K125AA - SMD Multilayer Ceramic Capacitor, 1 µF, 25 V, 0805 [2012 Metric], ± 10%, X5R, C Series | 1 | Digi-Key | 445-1419-1-ND | 1 | 30511 | 0.27 | 0.27 | USD
5 | Ceramic Capacitors | KEMET | C0805C180J5GACTU | 805 | CAP CER 18PF 50V C0G/NP0 0805 | 4 | Digi-Key | 399-1112-1-ND | 4 | 171703 | 0.14 | 0.56 | USD
6 | Uncategorized | Osram Opto | LGL29K-G2J1-24-Z | 603 | LED Uni-Color Green 572nm 2-Pin Chip 0603(1608Metric) T/R | 2 | Digi-Key | 475-2709-1-ND | 2 | 111435 | 0.42 | 0.84 | USD
7 | Uncategorized | Osram Opto | LOL29K-H2K1-24-Z | 603 | OSRAM - LO L29K-H2K1-24-Z - SMARTLED 0603 ORANGE | 2 | Digi-Key | 475-2740-1-ND |  | 0
8 | Schottky Diodes | ON Semiconductor / Fairchild | BAT54HT1G |  | Small Signal Schottky Diode, Single, 30 V, 200 mA, 800 mV, 600 mA, 150 C ;RoHS Compliant: Yes | 2 | Digi-Key | BAT54HT1GOSCT-ND | 2 | 317312 | 0.20 | 0.40 | USD
9 | Ferrite Beads and Chips | TDK | MPZ2012S601AT000 | 805 | FERRITE BEAD 600 OHM 0805 1LN | 3 | Digi-Key | 445-2206-1-ND | 3 | 195573 | 0.11 | 0.33 | USD
10 | Headers and Wire Housings | Harwin | M20-7820842 | SIL | 2.54mm (0.1") Pitch SIL Vertical PC Tail Socket Assembly, selective gold + tin, 8 contacts | 2 | Digi-Key | 952-1823-ND | 2 | 1174 | 1.10 | 2.20 | USD
11 | Headers and Wire Housings | Harwin | M20-7820646 | SIL | 06-WAY SIL VERT SOCKET L/FREE | 1 | Digi-Key | 952-1809-ND | 1 | 1771 | 0.96 | 0.96 | USD
12 | Headers and Wire Housings | Harwin | M20-7821046 | SIL | HARWIN - M20-7821046 - Board-To-Board Connector, M20 Series, Through Hole, Receptacle, 10, 2.54 mm, Tin Plated Contacts | 1 | Digi-Key | 952-1847-ND | 1 | 429 | 1.28 | 1.28 | USD
13 | Headers and Wire Housings | Amphenol ICC / FCI | 67997-106HLF |  | CONN HEADER 6POS .100 STR 30AU | 2 | Digi-Key | 609-3393-ND | 2 | 1596 | 1.78 | 3.56 | USD
14 | USB Connectors | AMPHENOL ICC (FCI) | 10118193-0001LF |  | CONN USB MICRO B RECPT SMT R/A | 1 | Digi-Key | 609-4616-1-ND | 1 | 132063 | 0.43 | 0.43 | USD
15 | Headers and Wire Housings | Amphenol ICC | 68000-103HLF |  | Conn Unshrouded Header HDR 3 POS 2.54mm Solder ST Thru-Hole Bulk | 2 | Digi-Key | 609-3461-ND | 2 | 44487 | 0.29 | 0.58 | USD
16 | Headers and Wire Housings | Amphenol FCI | 68001-204HLF |  | CONN HEADER VERT 4POS 2.54MM | 1 | Digi-Key | 609-3402-ND | 1 | 3312 | 0.38 | 0.38 | USD
17 | Fixed Inductors | KEMET | L1210R2R2MDWIT | 1210 | FIXED IND 2.2UH 2A 80 MOHM SMD | 1 | Digi-Key | 399-9598-1-ND | 1 | 491 | 0.55 | 0.55 | USD
18 | Connectors | Sullins | QPC02SXGN-RC | 100 | CONN JUMPER SHORTING .100" GOLD | 3 | Digi-Key | S9337-ND | 3 | 787620 | 0.10 | 0.30 | USD
19 | Chip SMD Resistors | Yageo | RC0805FR-07100KL | 805 | YAGEO RC0805FR-07100KL RES, THICK FILM, 100K, 1%, 0.125W, 0805, REEL | 1 | Digi-Key | 311-100KCRCT-ND | 1 | 4456706 | 0.10 | 0.10 | USD
20 | Chip SMD Resistors | Yageo | RC0805FR-07560RL | 805 | Surface Mount Thick Film Resistor, RC Series, 560 ohm, 125 mW, - 1%, 150 V, 0805 [2012 Metric] | 5 | Digi-Key | 311-560CRCT-ND | 5 | 190642 | 0.10 | 0.50 | USD
21 | Chip SMD Resistors | Yageo | RC0805FR-0710KL | 805 | RES SMD 10K OHM 1% 1/8W 0805 | 6 | Digi-Key | 311-10.0KCRCT-ND | 6 | 21750345 | 0.10 | 0.60 | USD
22 | Chip SMD Resistors | Yageo | RC0805FR-0722RL | 805 | RES SMD 22 OHM 1% 1/8W 0805 | 7 | Digi-Key | 311-22.0CRCT-ND | 7 | 514380 | 0.10 | 0.70 | USD
23 | Chip SMD Resistors | Yageo | RC0805JR-070RL | 805 | Surface Mount Thick Film Resistor, RC Series, 125 mW, - 5%, 150 V, 0805 [2012 Metric] | 1 | Digi-Key | 311-0.0ARCT-ND | 1 | 7869723 | 0.10 | 0.10 | USD
24 | Chip SMD Resistors | Yageo | RC0805FR-071ML | 805 | RES SMD 1M OHM 1% 1/8W 0805 | 2 | Digi-Key | 311-1.00MCRCT-ND | 2 | 3426364 | 0.10 | 0.20 | USD
25 | Chip SMD Resistors | Yageo | RC0805FR-071KL | 805 | RESISTOR, 0805 1K 1%, FULL REEL; Product Range:YAGEO - RC Series; Resistance:1kohm; Power Rating:125mW; Resistance Tolerance:± 1%; Resistor Case Style:0805 [2012 Metric]; Resistor Element Material:Thick Film; Temperature Coefficient:± 250ppm/°C; Voltage Rating:150V; Packaging:Tape & Reel; MSL:-; SVHC:No SVHC (16-Dec-2013); External Depth:0.55mm; External Length / Height:2mm; External Width:1.25mm; No. of Pins:2; Operating Temperature Max:155°C; Operating Temperature Min:-55°C; Operating Temperature Range:-55°C to +155°C; Reel Quantity:5000; Resistor Mounting:SMD; Series:RC12H; Temperature Coef | 3 | Digi-Key | 311-1.00KCRCT-ND | 3 | 19269677 | 0.10 | 0.30 | USD
26 | Connectors | 3M | 7010501790 |  | CONN IC DIP SOCKET 28POS TIN | 1 | Digi-Key | 3M5480-ND | 1 | 4576 | 0.79 | 0.79 | USD
27 | Pushbutton Switches | TE Connectivity | FSM4JH |  | SWITCH TACTILE SPST-NO 0.05A 24V | 2 | Digi-Key | 450-1650-ND | 2 | 14134 | 0.10 | 0.20 | USD
28 |  | Microchip / Atmel | ATMEGA328P-PU |  | ATMEGA328P-PU; 8 bit Microcontroller AVR 20MHz 1; 32kb Flash; 2kb RAM; I2C SPI 2 | 1 | Digi-Key | ATMEGA328P-PU-ND | 1 | 5534 | 2.08 | 2.08 | USD
29 | Microcontrollers | Microchip / Atmel | ATMEGA16U2-AU | TQFP | ATmega Series 16 KB Flash 512 B RAM 16 MHz 8-Bit Microcontroller - TQFP-32 | 1 | Digi-Key | ATMEGA16U2-AU-ND | 1 | 1742 | 2.45 | 2.45 | USD
30 | Voltage Regulators - Linear | Texas Instruments | TL1963A-33DCQR | SOT-223 | IC REG LINEAR 3.3V 1.5A SOT223-6 | 1 | Digi-Key | 296-24534-1-ND | 1 | 3291 | 2.80 | 2.80 | USD
31 | Logic Gates | Texas Instruments | SN74AHC1G09DBVR | SOT-23 | TEXAS INSTRUMENTS - SN74AHC1G09DBVR - AND Gate, 74AHC1G09, 2 Input, 2 V to 5.5 V, SOT-23-5 | 4 | Digi-Key | 296-29202-1-ND | 4 | 39429 | 0.32 | 1.28 | USD
32 | Crystals | Abracon | ABM7-10.000MHZ-D2Y-T | SMD/SMT | CRYSTAL 10.0000MHZ 18PF SMD | 1 | Digi-Key | 535-9833-1-ND | 1 | 35920 | 1.00 | 1.00 | USD
33 | Crystals | Abracon | ABM7-8.000MHZ-D2Y-T | CSMD | ABRACON - ABM7-8.000MHZ-D2Y-T - Crystal, Miniature, 8 MHz, SMD, 6mm x 3.5mm, 30 ppm, 18 pF, 20 ppm, ABM7 Series | 1 | Digi-Key | 535-9831-1-ND | 1 | 72349 | 1.00 | 1.00 | USD
34 | Varistors | Bourns | CG0603MLC-05E | 603 | VARISTOR 0603 | 2 | Digi-Key | CG0603MLC-05ECT-ND | 2 | 8527 | 0.51 | 1.02 | USD
 |  |  |  |  |  | 95 |  |  | 93 |  |  | 32.41
Approved |  |  |  | Notes
 |  |  |  |  |  | 1 | pcs: | Total |  | 32.41 |  | USD
 |  |  |  |  |  |  |  | Price for 1pcs |  | 32.41 |  | USD

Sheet: Project Information
Project Full Path | C:\Users\cedri\Desktop\FEDEVEL Academy\28 Pins\Design Files\V1I1\28Pins_Project_V1I1.PrjPcb
Project Filename | 28Pins_Project_V1I1.PrjPcb
Variant Name | 5V/3V3
Data-Source Filename | 28Pins_Project_V1I1.PrjPcb
Data-Source Full Path | C:\Users\cedri\Desktop\FEDEVEL Academy\28 Pins\Design Files\V1I1\28Pins_Project_V1I1.PrjPcb
Title | 28PINS_Purchasing_BOM for Variant [5V/3V3] of Project [28Pins_Project_V1I1.PrjPcb] (No PCB Document Selected)
Total Quantity | 95
Report Time | 17:50
Report Date | 22/06/2020
Report Date & Tine | 22/06/2020 17:50
Output Name | 28PINS_Purchasing_BOM
Output Type | BOM_PartType
Output Generator Name | BOM
Output Generator Description | Bill of Materials

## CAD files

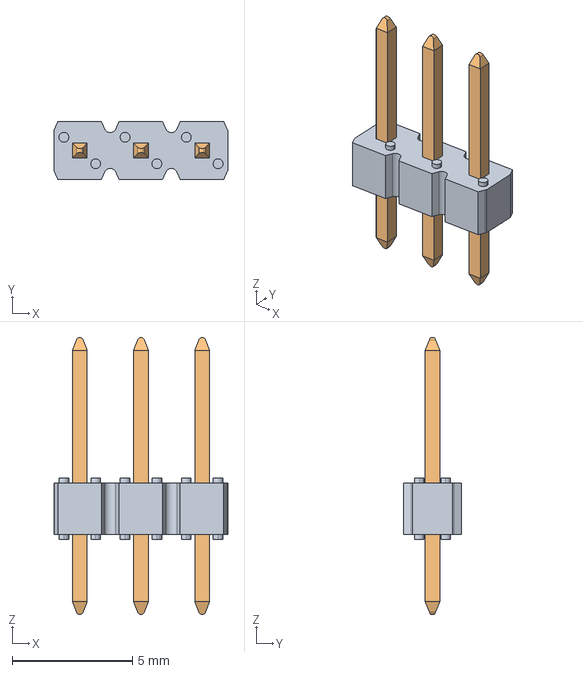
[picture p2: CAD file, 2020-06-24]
Design Files/V1I1/3d models/HDR_1x3_White.stp
7.22 x 2.41 x 11.5 mm
77310_Y16 x 3

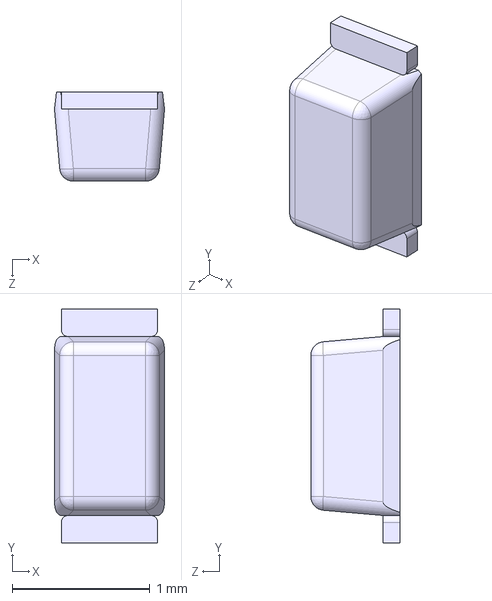
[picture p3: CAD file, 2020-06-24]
Design Files/V1I1/3d models/LED SMD 0603 super red.step
0.8 x 1.70 x 0.65 mm

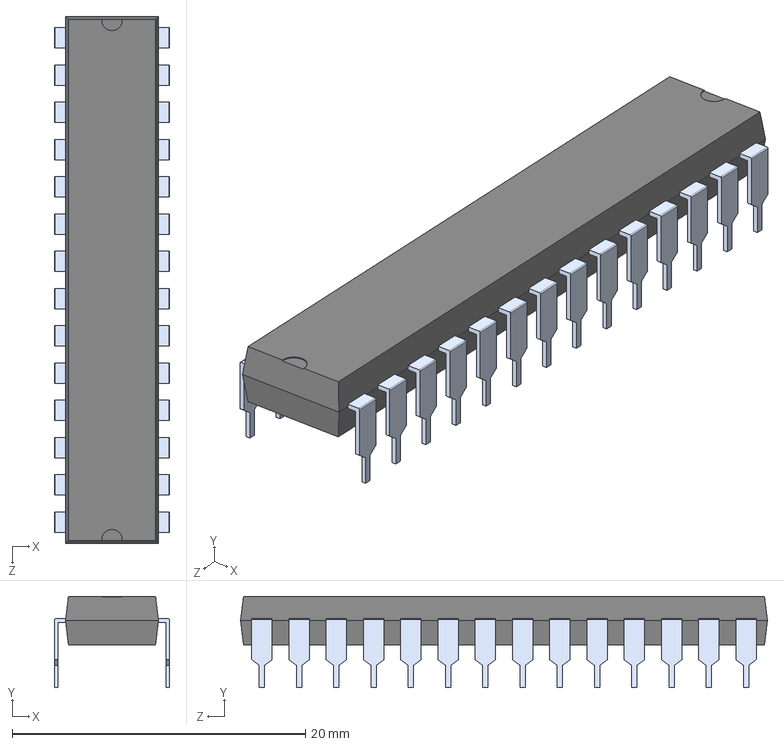
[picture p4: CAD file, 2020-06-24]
Design Files/V1I1/3d models/28 pin dip.step
7.87 x 6.22 x 35.9 mm

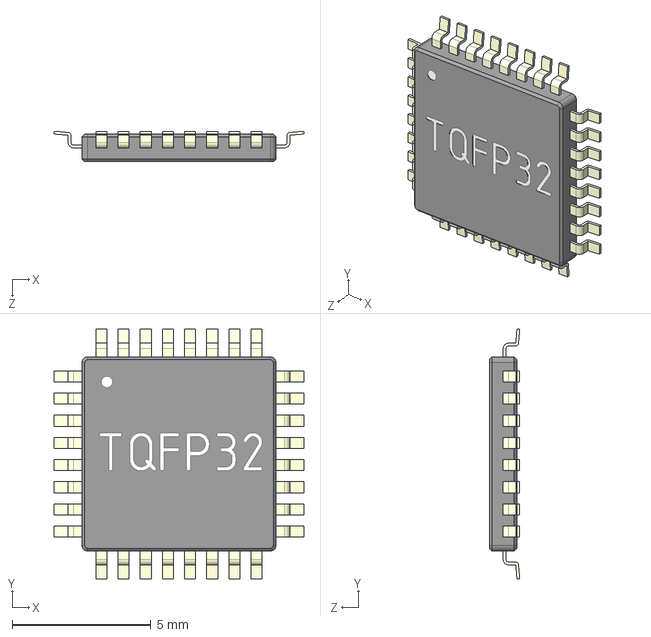
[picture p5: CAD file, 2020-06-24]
Design Files/V1I1/3d models/TQFP32-1.step
9.02 x 9.02 x 1.10 mm

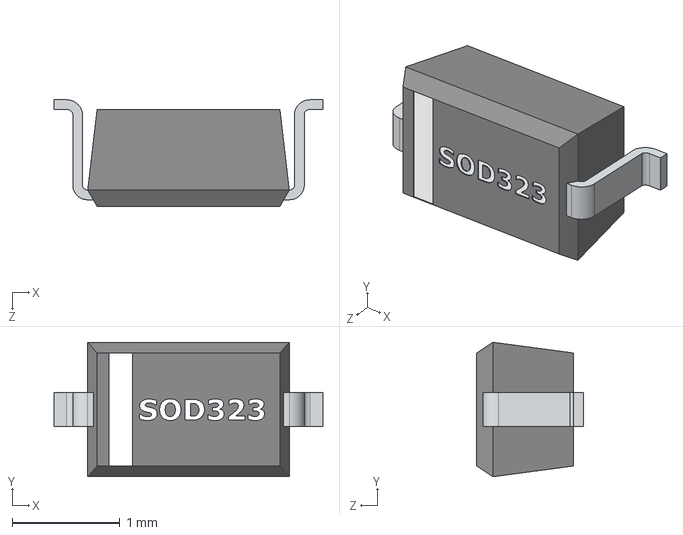
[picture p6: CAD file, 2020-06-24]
Design Files/V1I1/3d models/diod-SOD323.step
2.50 x 1.25 x 0.99 mm

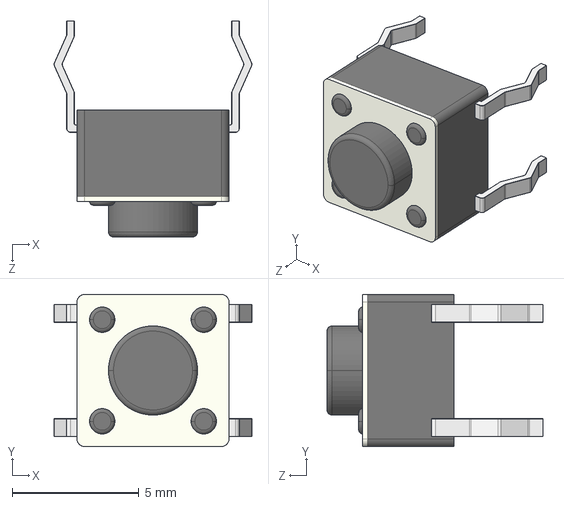
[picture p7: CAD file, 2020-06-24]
Design Files/V1I1/3d models/BP-FSM4JLH(1825910-5).step
7.80 x 5.99 x 8.51 mm

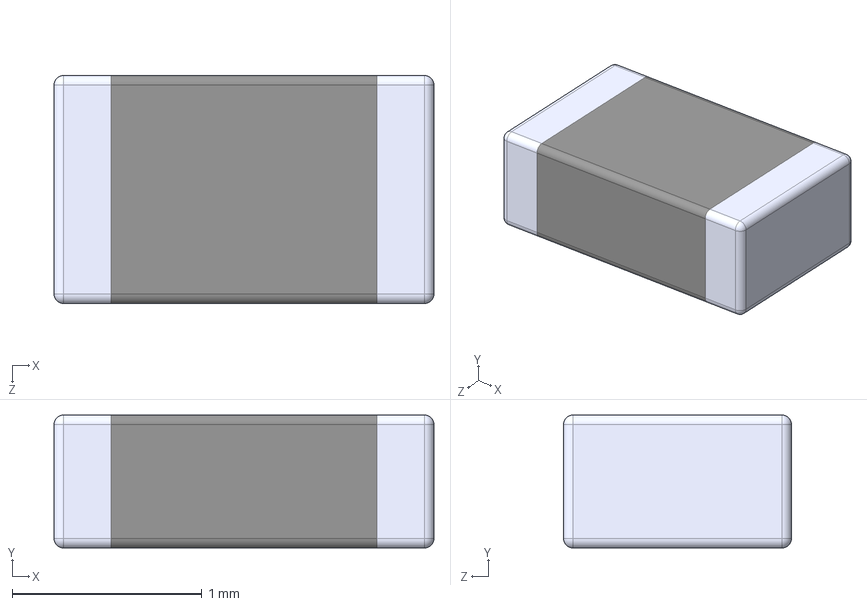
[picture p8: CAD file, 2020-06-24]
Design Files/V1I1/3d models/RESC2012X70N.step
2.00 x 0.7 x 1.20 mm

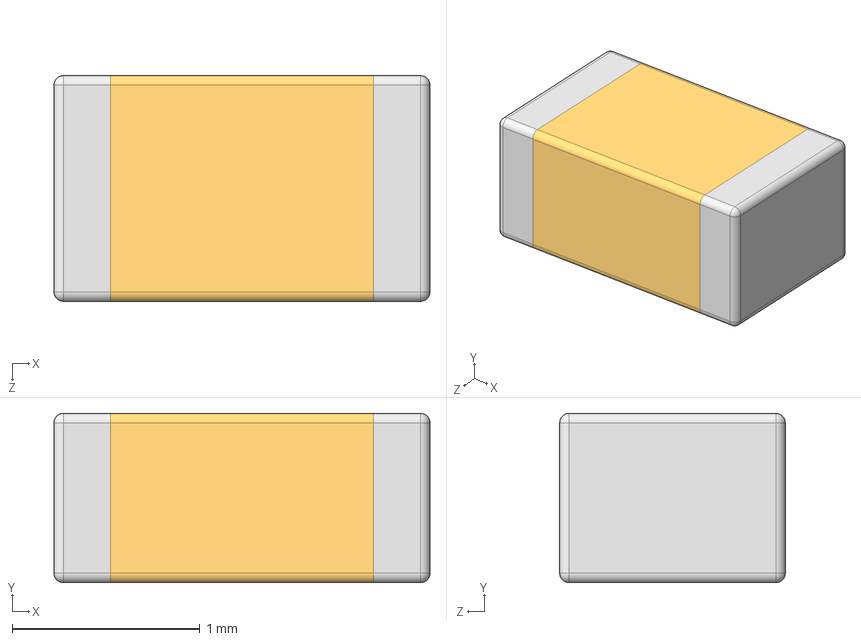
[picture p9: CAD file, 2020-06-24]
Design Files/V1I1/3d models/CAPC2012X90N EIA 0805.step
2.00 x 0.9 x 1.20 mm

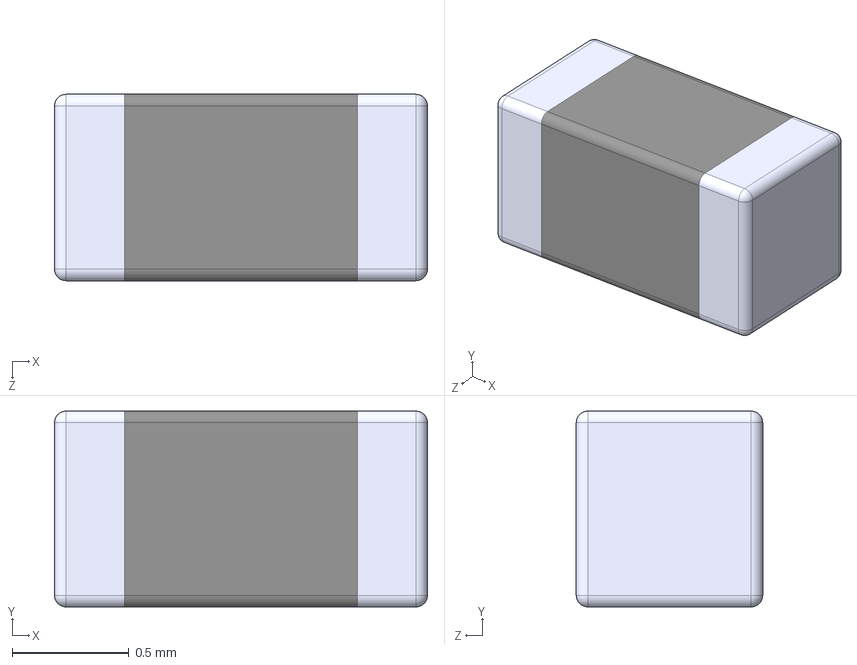
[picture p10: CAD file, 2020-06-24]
Design Files/V1I1/3d models/varistor_R0603.step
1.60 x 0.84 x 0.8 mm

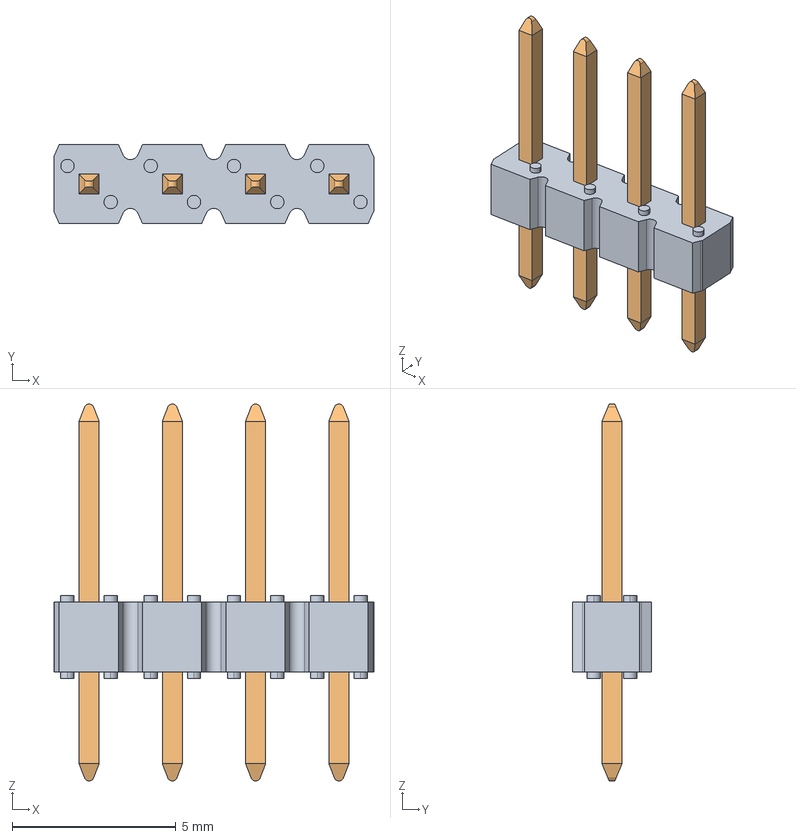
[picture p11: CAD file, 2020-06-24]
Design Files/V1I1/3d models/HDR_1x4_White.stp
9.76 x 2.41 x 11.5 mm

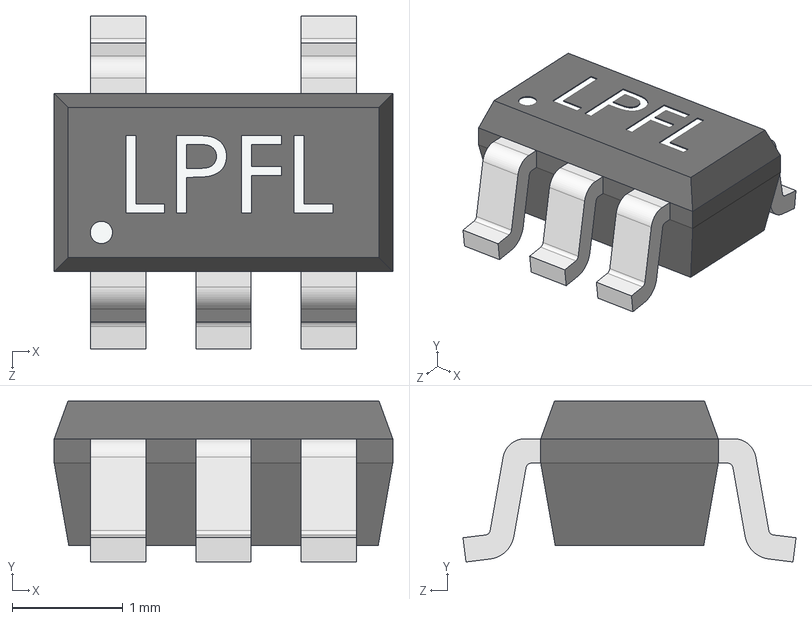
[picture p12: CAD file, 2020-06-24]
Design Files/V1I1/3d models/DBV.step
3.05 x 1.45 x 3.00 mm

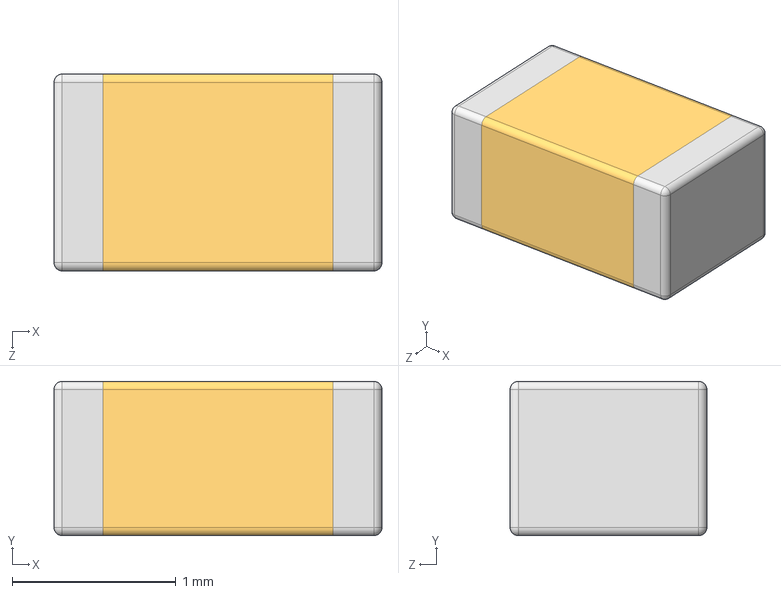
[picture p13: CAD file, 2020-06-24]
Design Files/V1I1/3d models/CAPC2012X94N EIA 0805.step
2.00 x 0.94 x 1.20 mm

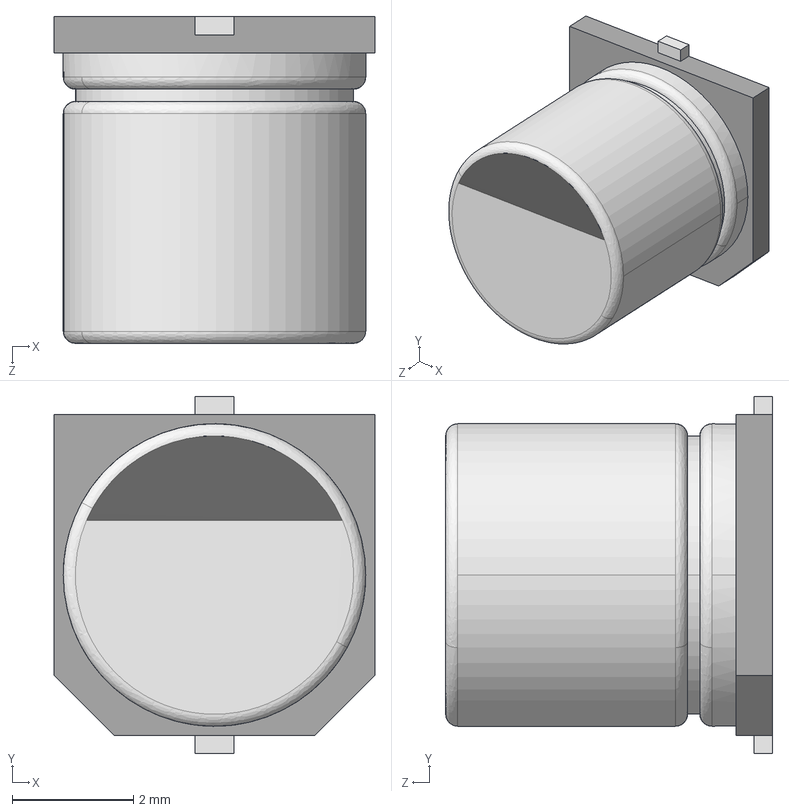
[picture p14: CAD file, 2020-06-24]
Design Files/V1I1/3d models/capacitor size C.step
5.30 x 5.90 x 5.41 mm

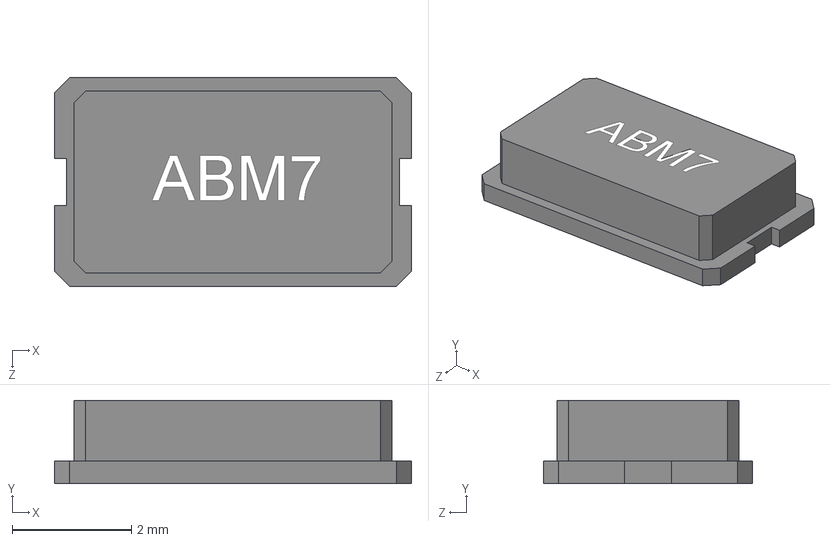
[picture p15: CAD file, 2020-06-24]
Design Files/V1I1/3d models/ABM7.STEP
5.99 x 1.40 x 3.51 mm

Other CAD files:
Design Files/V1I1/3d models/Regulator_TPS73701DCQ.step
Design Files/V1I1/3d models/dil_socket.stp
Design Files/V1I1/3d models/m20-7820646_asm.stp
Design Files/V1I1/3d models/m20-7820842_asm.stp
Design Files/V1I1/3d models/961204-6404-XX.stp
Design Files/V1I1/3d models/961206-6404-XX.stp
Design Files/V1I1/3d models/m20-7821046_asm.stp

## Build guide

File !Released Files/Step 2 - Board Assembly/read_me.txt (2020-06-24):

Place following files here:

- Mechanical Drawing (Board dimensions, holes position, ..)
- TOP and BOTTOM Assembly Drawing (Component position with Reference Designator)
- TOP and BOTTOM VIEW (shows board outline, assembly layer, TOP + BOTTOM layers)
- Bill of Materials (grouped by component type)
- Component reference BOM (each component on one line: Designator, Description, Manufacturer 1,
  Manufacturer, Part Number 1, Package / Case, Supplier 1, Supplier Part Number 1)
- Component reference BOM (as above) grouped by component type.
- Pick and Place
- TOP and BOTTOM Layer + TOP and BOTTOM Paste Gerber Files (for stencil - if panel is done in a PCB house, ask them later for the top/bottom layers and paste for the panel)
- PDF 3D Model

!!! BE AWARE !!! If you use a VARIANT were you replace a component by other component,
THIS WILL NOT BE REFLECTED IN ASSEMBLY DRAWING and component will look like not fitted.
This may be a bug in Altium 14.3. Use a TEMP Schematic to generate the ASM DRWG. SAME
FOR PICK & PLACE!!

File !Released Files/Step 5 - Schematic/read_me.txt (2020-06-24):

Update Schematic Cover Page to RELEASED DD-MMM-YYYY
Place here PDF version of schematic, if possible one for each BOM variant.

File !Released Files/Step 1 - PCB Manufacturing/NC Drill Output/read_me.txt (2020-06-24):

Place here drill files and documents which explain it (e.g. for HDI PCB you can put here pdf showing drills for each layer pair)

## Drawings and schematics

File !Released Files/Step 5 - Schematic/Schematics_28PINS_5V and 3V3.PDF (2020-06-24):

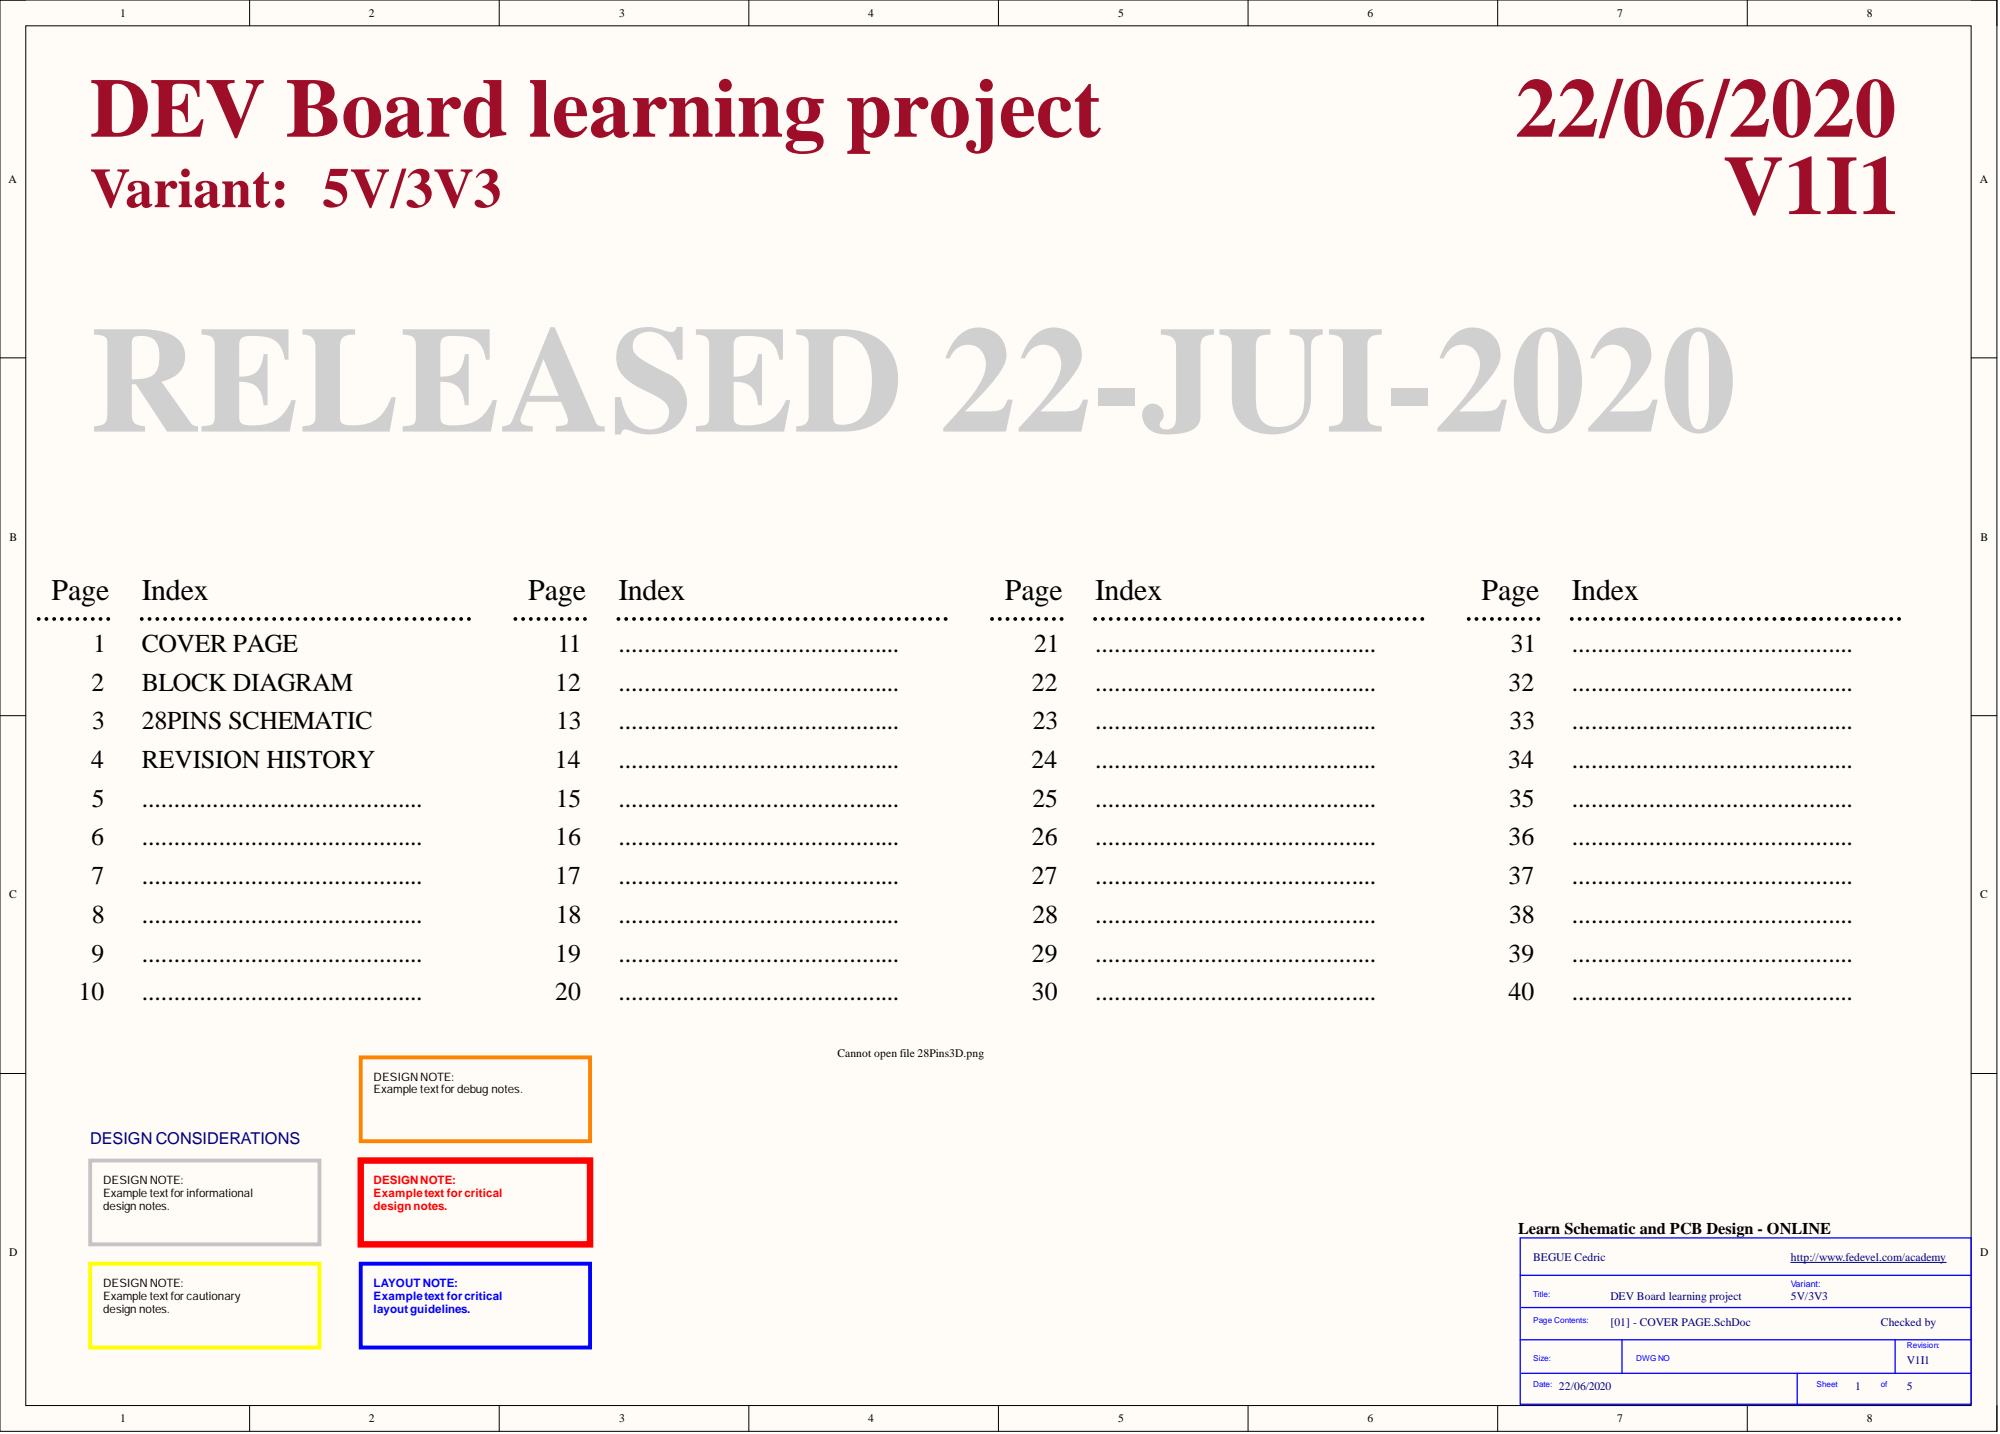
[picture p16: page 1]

Cannot open file 28Pins3D.png

DESIGN NOTE:
Example text for debug notes.

Example text for informational
design notes.

Example text for critical

Learn Schematic and PCB Design - ONLINE

http://www.fedevel.com/academy

Example text for cautionary

LAYOUT NOTE:
layout guidelines.

DEV Board learning project

Size: | DWG NO | Revision: V1I1

Date: | Sheet of

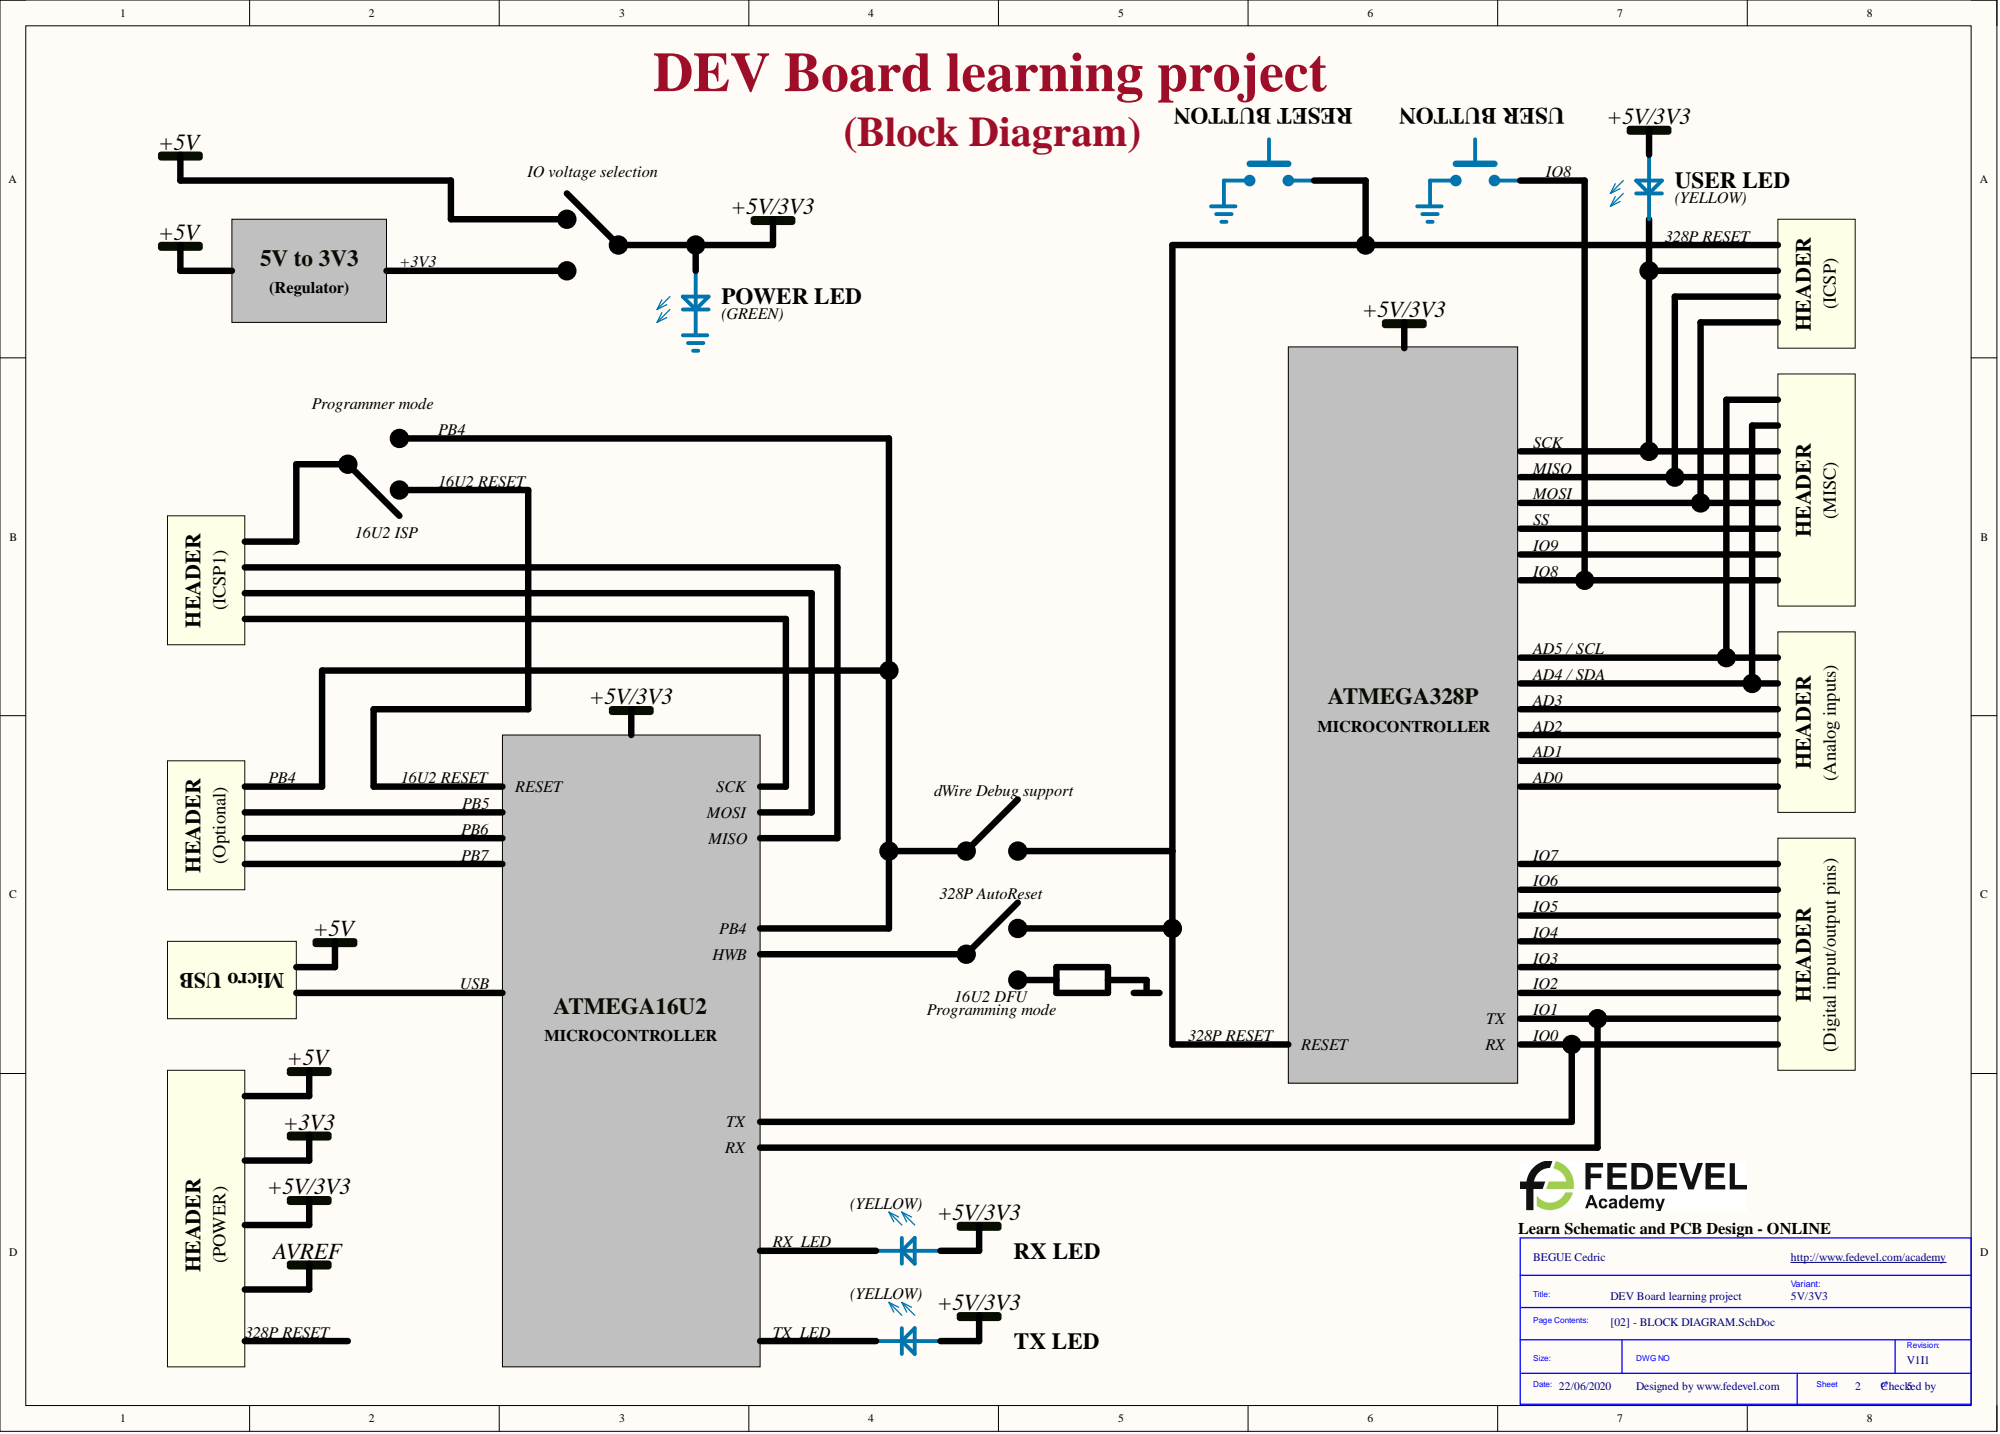
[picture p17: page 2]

DEV Board learning project

MISO
MOSI
SS
IO9
IO8

AD5 / SCL
AD4 / SDA

Learn Schematic and PCB Design - ONLINE

http://www.fedevel.com/academy

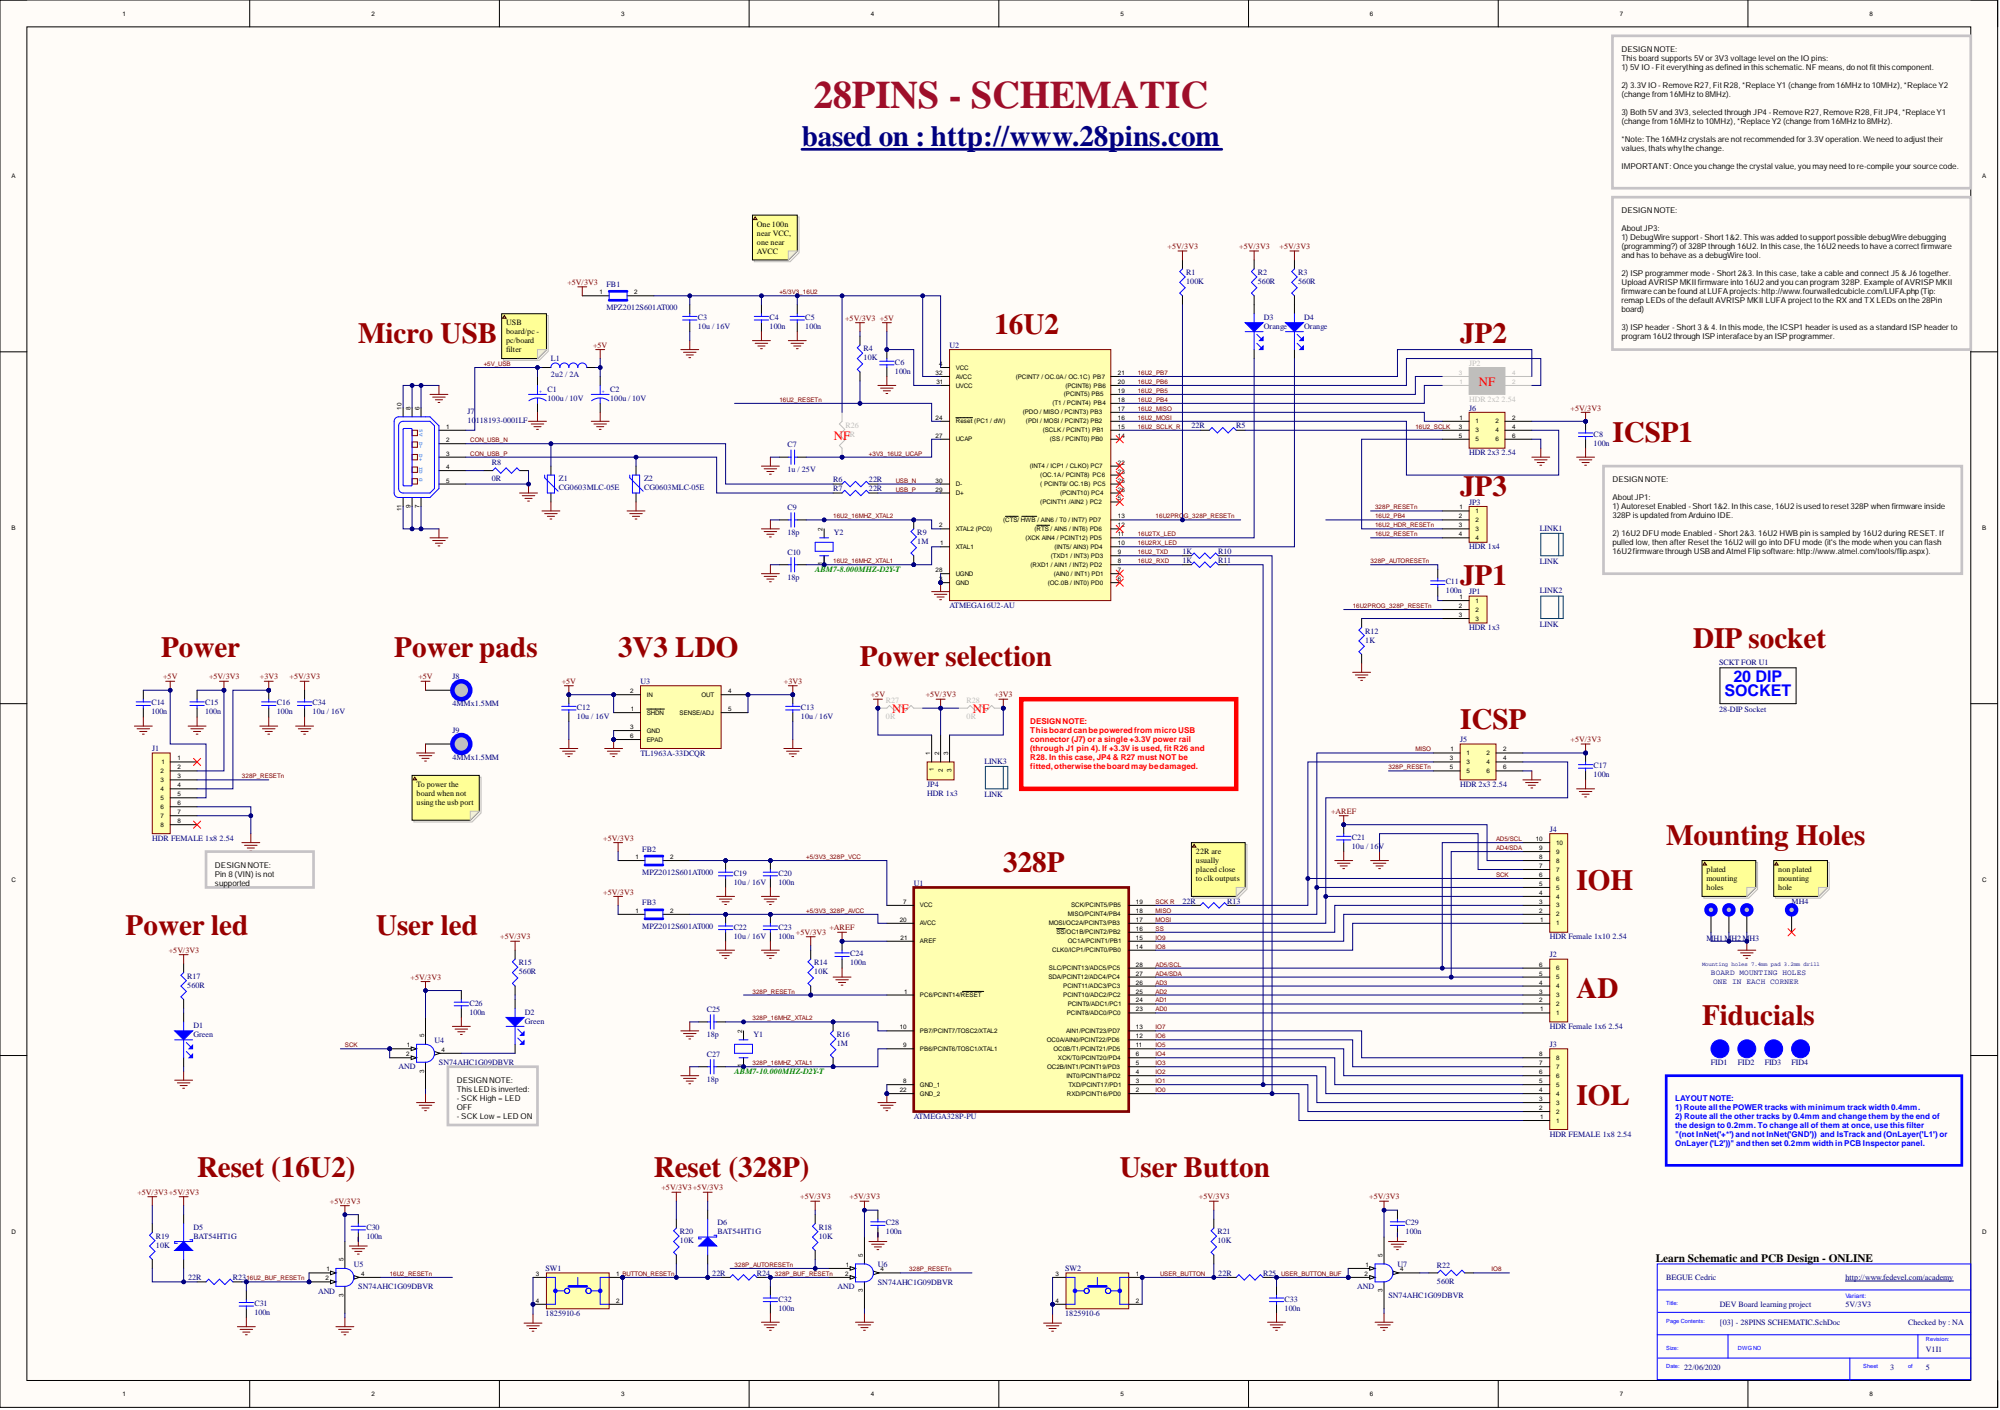
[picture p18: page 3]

DESIGN NOTE:
This board supports 5V or 3V3 voltage level on the IO pins:
1) 5V IO - Fit everything as defined in this schematic. NF means, do not fit this component.

28PINS - SCHEMATIC
based on : http://www.28pins.com

2) 3.3V IO - Remove R27, Fit R28,*Replace Y1 (change from 16MHz to 10MHz), *Replace Y2
(change from 16MHz to 8MHz).

3) Both 5V and 3V3, selected through JP4 - Remove R27, Remove R28, Fit JP4,*Replace Y1
(change from 16MHz to 10MHz), *Replace Y2 (change from 16MHz to 8MHz).

*Note: The 16MHz crystals are not recommended for 3.3V operation. We need to adjust their
values, thats why the change.

IMPORTANT: Once you change the crystal value, you may need to re-compile your source code.

About JP3:
1) DebugWire support - Short 1&2. This was added to support possible debugWire debugging
(programming?) of 328P through 16U2. In this case, the 16U2 needs to have a correct firmware
and has to behave as a debugWire tool.

2) ISP programmer mode - Short 2&3. In this case, take a cable and connect J5 & J6 together.
Upload AVRISP MKII firmware into 16U2 and you can program 328P. Example of AVRISP MKII
firmware can be found at LUFA projects: http://www.fourwalledcubicle.com/LUFA.php (Tip:
remap LEDs of the default AVRISP MKII LUFA project to the RX and TX LEDs on the 28Pin
board)

3) ISP header - Short 3 & 4. In this mode, the ICSP1 header is used as a standard ISP header to
program 16U2 through ISP interaface by an ISP programmer.

UVCC 31 AVCC 32 | 16U2_PB6 | 1 1 2 4 NF | 2 3 3 4

16U2_MISO
16U2_MOSI

UCAP 27 | | 16U2PROG_328P_RESETn 16U2TX_LED | 16U2_SCLK

3 | CON_USB_P | C7

About JP1:
1) Autoreset Enabled - Short 1&2. In this case, 16U2 is used to reset 328P when firmware inside
328P is updated from Arduino IDE.

2) 16U2 DFU mode Enabled - Short 2&3. 16U2 HWB pin is sampled by 16U2 during RESET. If
pulled low, then after Reset the 16U2 will go into DFU mode (it's the mode when you can flash
16U2 firmware through USB and Atmel Flip software: http://www.atmel.com/tools/flip.aspx ).

DIP socket Power selection

This board can be powered from micro USB
connector (J7) or a single +3.3V power rail
(through J1 pin 4). If +3.3V is used, fit R26 and
R28. In this case, JP4 & R27 must NOT be
fitted, otherwise the board may be damaged.

To power the
board when not
using the usb port

AD5/SCL
AD4/SDA

Pin 8 (VIN) is not
supported

SCK R 22R | R13

AVCC 20 | | MISO

PC6/PCINT14/RESET 1 | | IO8

Mounting holes 7.4mm pad 3.2mm drill
BOARD MOUNTING HOLES
ONE IN EACH CORNER
Fiducials

PB7/PCINT7/TOSC2/XTAL2 10 | AD1

This LED is inverted:
- SCK High = LED
OFF
- SCK Low = LED ON

LAYOUT NOTE:
1) Route all the POWER tracks with minimum track width 0.4mm.
2) Route all the other tracks by 0.4mm and change them by the end of
the design to 0.2mm. To change all of them at once, use this filter
"(not InNet('+*') and not InNet('GND')) and IsTrack and (OnLayer('L1') or
OnLayer('L2'))" and then set 0.2mm width in PCB Inspector panel.

Learn Schematic and PCB Design - ONLINE

http://www.fedevel.com/academy

DEV Board learning project

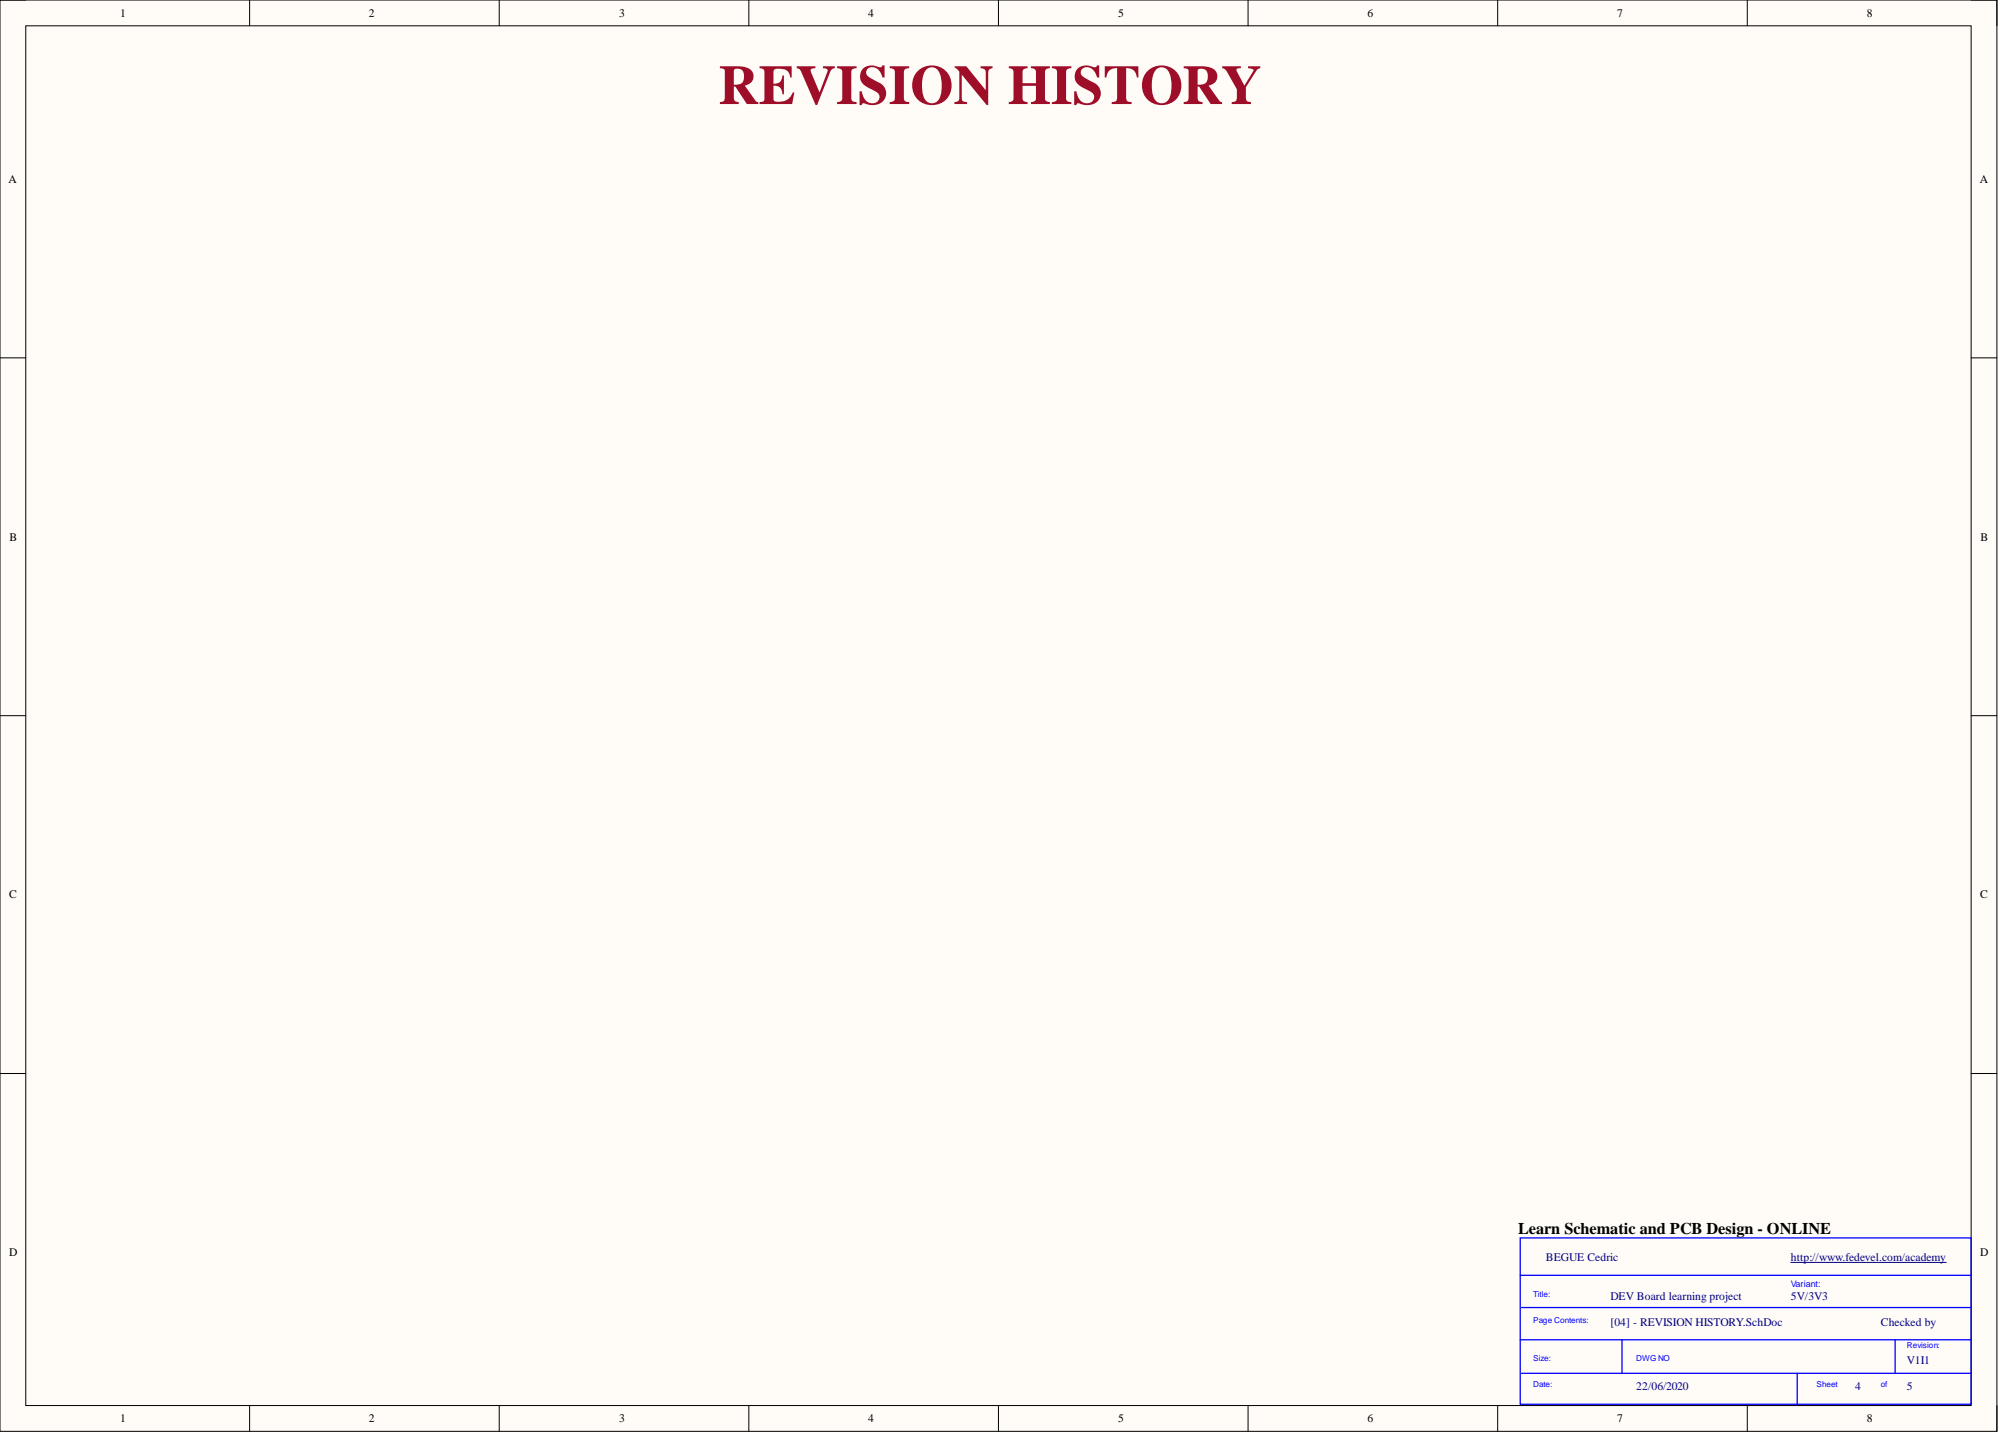
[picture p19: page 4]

Learn Schematic and PCB Design - ONLINE

http://www.fedevel.com/academy

DEV Board learning project

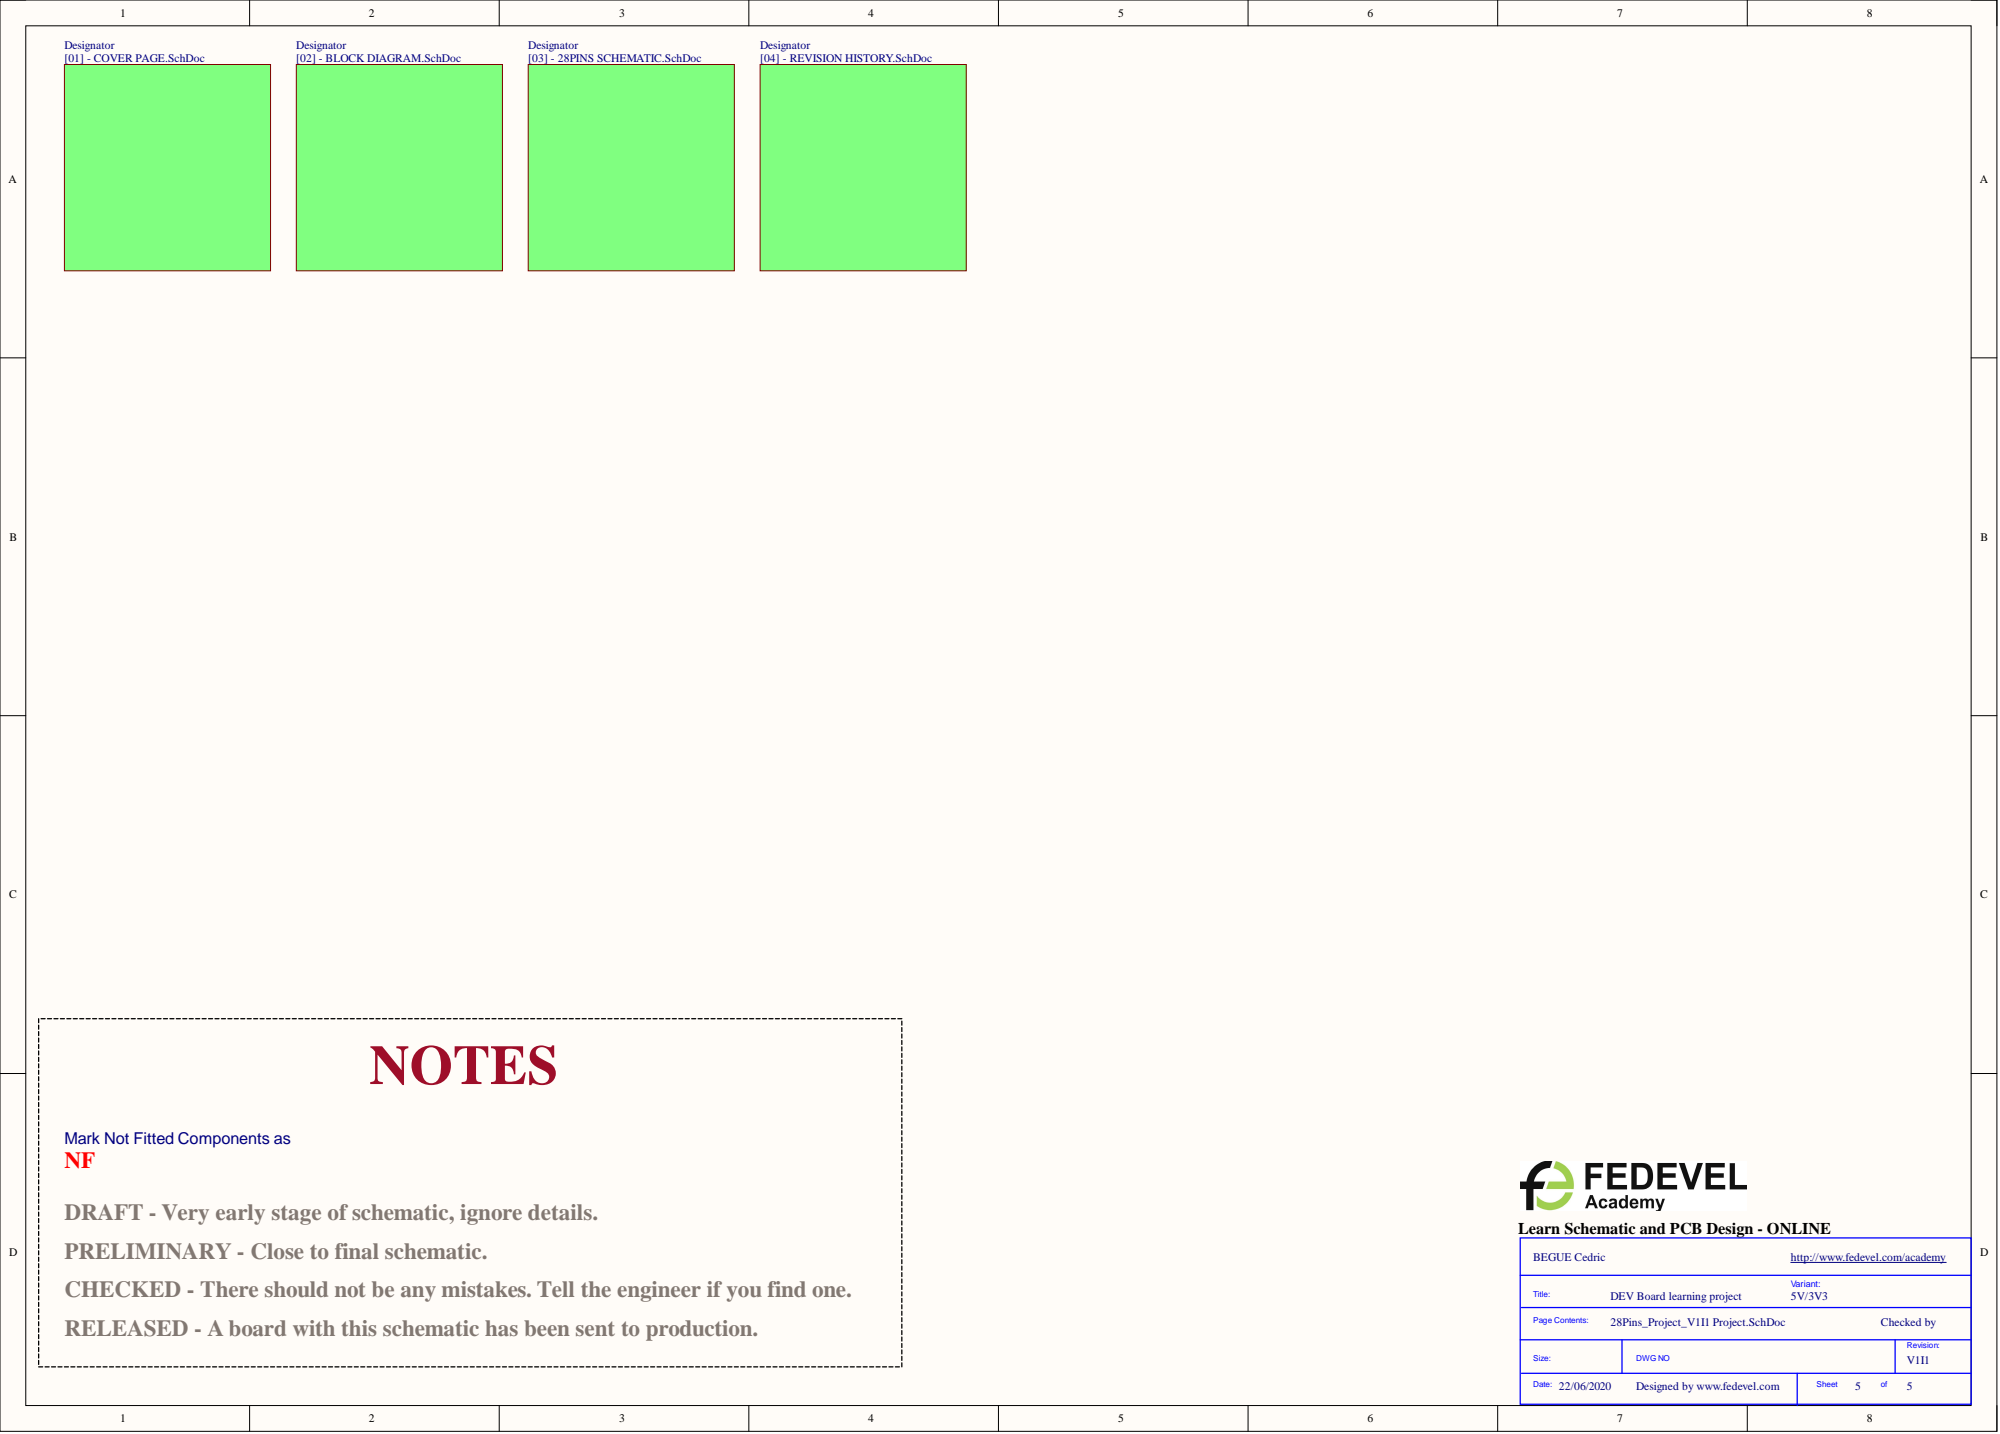
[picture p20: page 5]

Mark Not Fitted Components as

DRAFT - Very early stage of schematic, ignore details.
PRELIMINARY - Close to final schematic.
CHECKED - There should not be any mistakes. Tell the engineer if you find one.
RELEASED - A board with this schematic has been sent to production.

Learn Schematic and PCB Design - ONLINE

http://www.fedevel.com/academy

DEV Board learning project

Designed by www.fedevel.com

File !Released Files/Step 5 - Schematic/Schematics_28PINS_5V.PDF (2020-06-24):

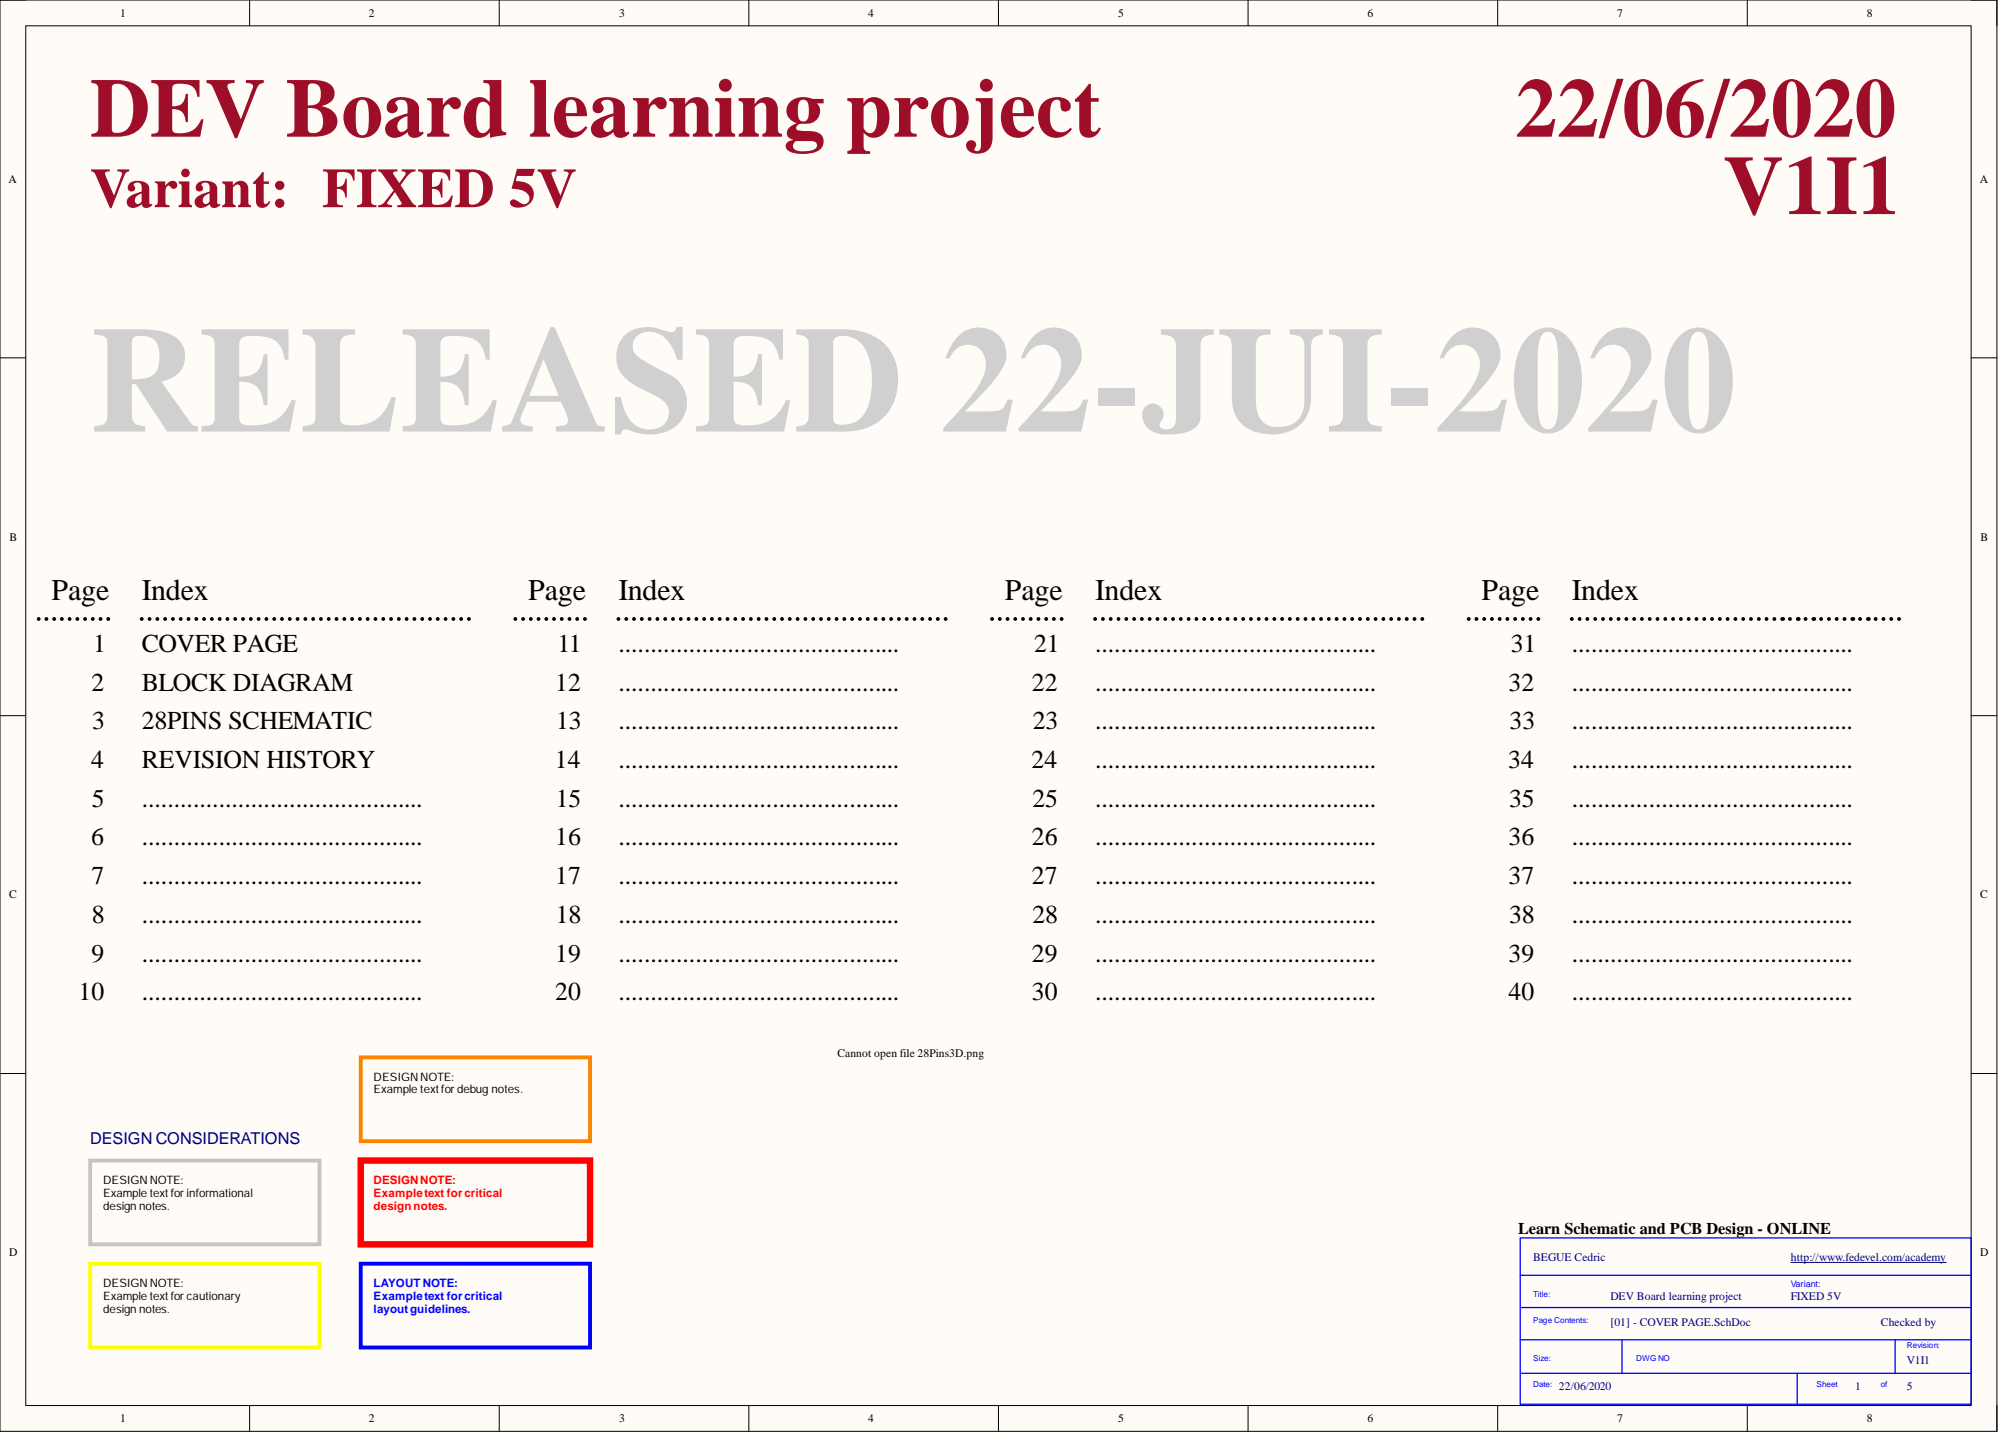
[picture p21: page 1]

Cannot open file 28Pins3D.png

DESIGN NOTE:
Example text for debug notes.

Example text for informational
design notes.

Example text for critical

Learn Schematic and PCB Design - ONLINE

http://www.fedevel.com/academy

Example text for cautionary

LAYOUT NOTE:
layout guidelines.

DEV Board learning project

Size: | DWG NO | Revision: V1I1

Date: | Sheet of

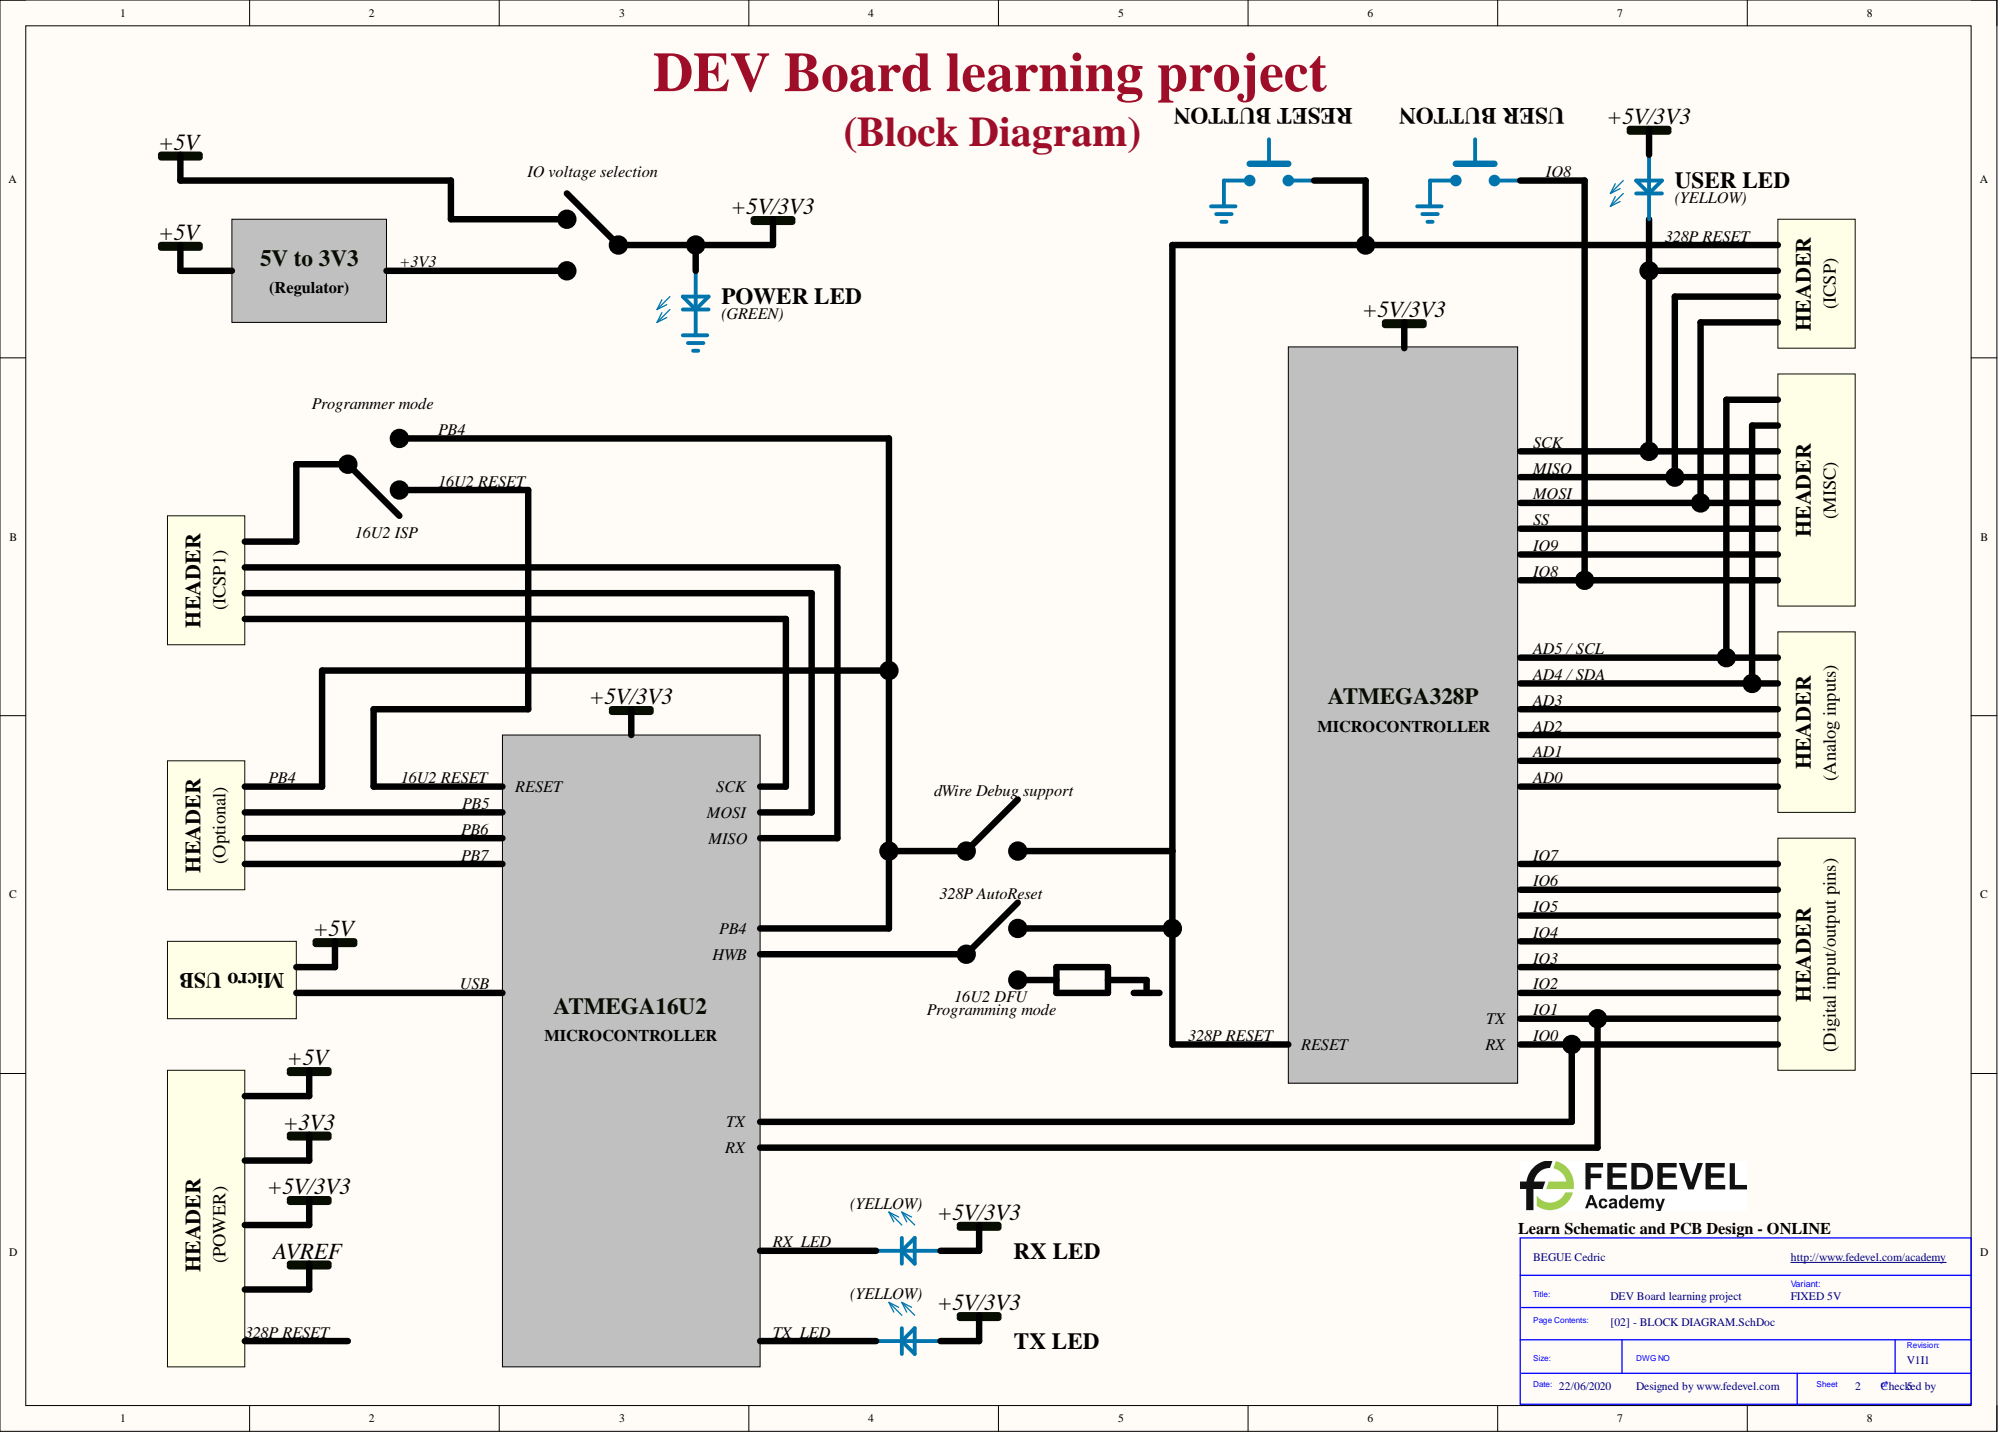
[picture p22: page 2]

DEV Board learning project

MISO
MOSI
SS
IO9
IO8

AD5 / SCL
AD4 / SDA

Learn Schematic and PCB Design - ONLINE

http://www.fedevel.com/academy

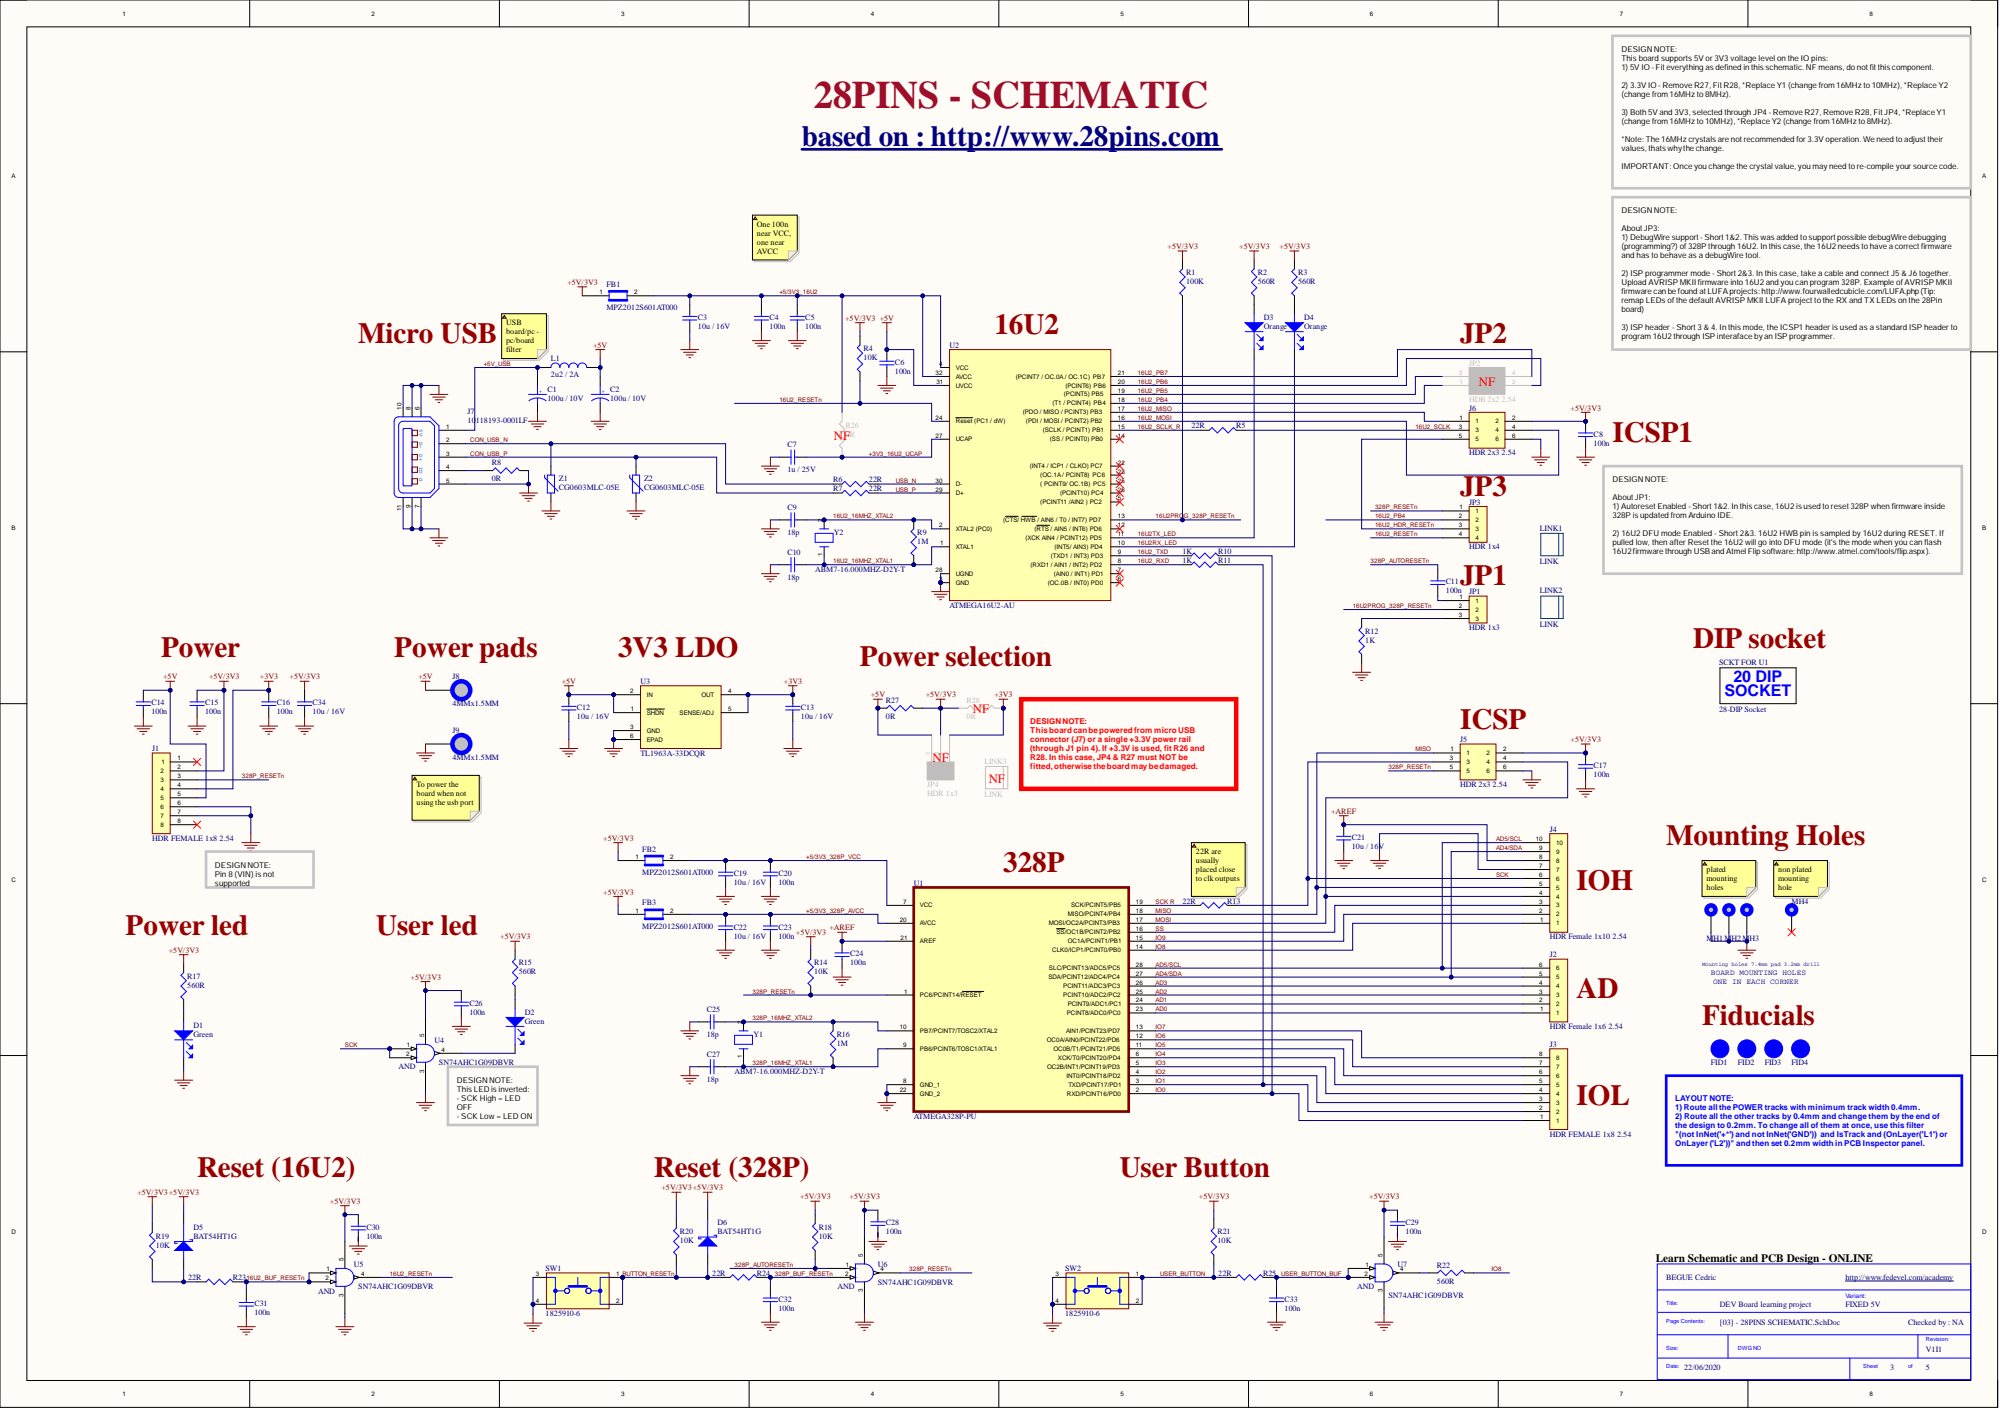
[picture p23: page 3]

DESIGN NOTE:
This board supports 5V or 3V3 voltage level on the IO pins:
1) 5V IO - Fit everything as defined in this schematic. NF means, do not fit this component.

28PINS - SCHEMATIC
based on : http://www.28pins.com

2) 3.3V IO - Remove R27, Fit R28,*Replace Y1 (change from 16MHz to 10MHz), *Replace Y2
(change from 16MHz to 8MHz).

3) Both 5V and 3V3, selected through JP4 - Remove R27, Remove R28, Fit JP4,*Replace Y1
(change from 16MHz to 10MHz), *Replace Y2 (change from 16MHz to 8MHz).

*Note: The 16MHz crystals are not recommended for 3.3V operation. We need to adjust their
values, thats why the change.

IMPORTANT: Once you change the crystal value, you may need to re-compile your source code.

About JP3:
1) DebugWire support - Short 1&2. This was added to support possible debugWire debugging
(programming?) of 328P through 16U2. In this case, the 16U2 needs to have a correct firmware
and has to behave as a debugWire tool.

2) ISP programmer mode - Short 2&3. In this case, take a cable and connect J5 & J6 together.
Upload AVRISP MKII firmware into 16U2 and you can program 328P. Example of AVRISP MKII
firmware can be found at LUFA projects: http://www.fourwalledcubicle.com/LUFA.php (Tip:
remap LEDs of the default AVRISP MKII LUFA project to the RX and TX LEDs on the 28Pin
board)

3) ISP header - Short 3 & 4. In this mode, the ICSP1 header is used as a standard ISP header to
program 16U2 through ISP interaface by an ISP programmer.

UVCC 31 AVCC 32 | 16U2_PB6 | 1 1 2 4 NF | 2 3 3 4

16U2_MISO
16U2_MOSI

UCAP 27 | | 16U2PROG_328P_RESETn 16U2TX_LED | 16U2_SCLK

3 | CON_USB_P | C7

About JP1:
1) Autoreset Enabled - Short 1&2. In this case, 16U2 is used to reset 328P when firmware inside
328P is updated from Arduino IDE.

2) 16U2 DFU mode Enabled - Short 2&3. 16U2 HWB pin is sampled by 16U2 during RESET. If
pulled low, then after Reset the 16U2 will go into DFU mode (it's the mode when you can flash
16U2 firmware through USB and Atmel Flip software: http://www.atmel.com/tools/flip.aspx ).

DIP socket Power selection

This board can be powered from micro USB
connector (J7) or a single +3.3V power rail
(through J1 pin 4). If +3.3V is used, fit R26 and
R28. In this case, JP4 & R27 must NOT be
fitted, otherwise the board may be damaged.

To power the
board when not
using the usb port

AD5/SCL
AD4/SDA

Pin 8 (VIN) is not
supported

SCK R 22R | R13

AVCC 20 | | MISO

PC6/PCINT14/RESET 1 | | IO8

Mounting holes 7.4mm pad 3.2mm drill
BOARD MOUNTING HOLES
ONE IN EACH CORNER
Fiducials

PB7/PCINT7/TOSC2/XTAL2 10 | AD1

This LED is inverted:
- SCK High = LED
OFF
- SCK Low = LED ON

LAYOUT NOTE:
1) Route all the POWER tracks with minimum track width 0.4mm.
2) Route all the other tracks by 0.4mm and change them by the end of
the design to 0.2mm. To change all of them at once, use this filter
"(not InNet('+*') and not InNet('GND')) and IsTrack and (OnLayer('L1') or
OnLayer('L2'))" and then set 0.2mm width in PCB Inspector panel.

Learn Schematic and PCB Design - ONLINE

http://www.fedevel.com/academy

DEV Board learning project

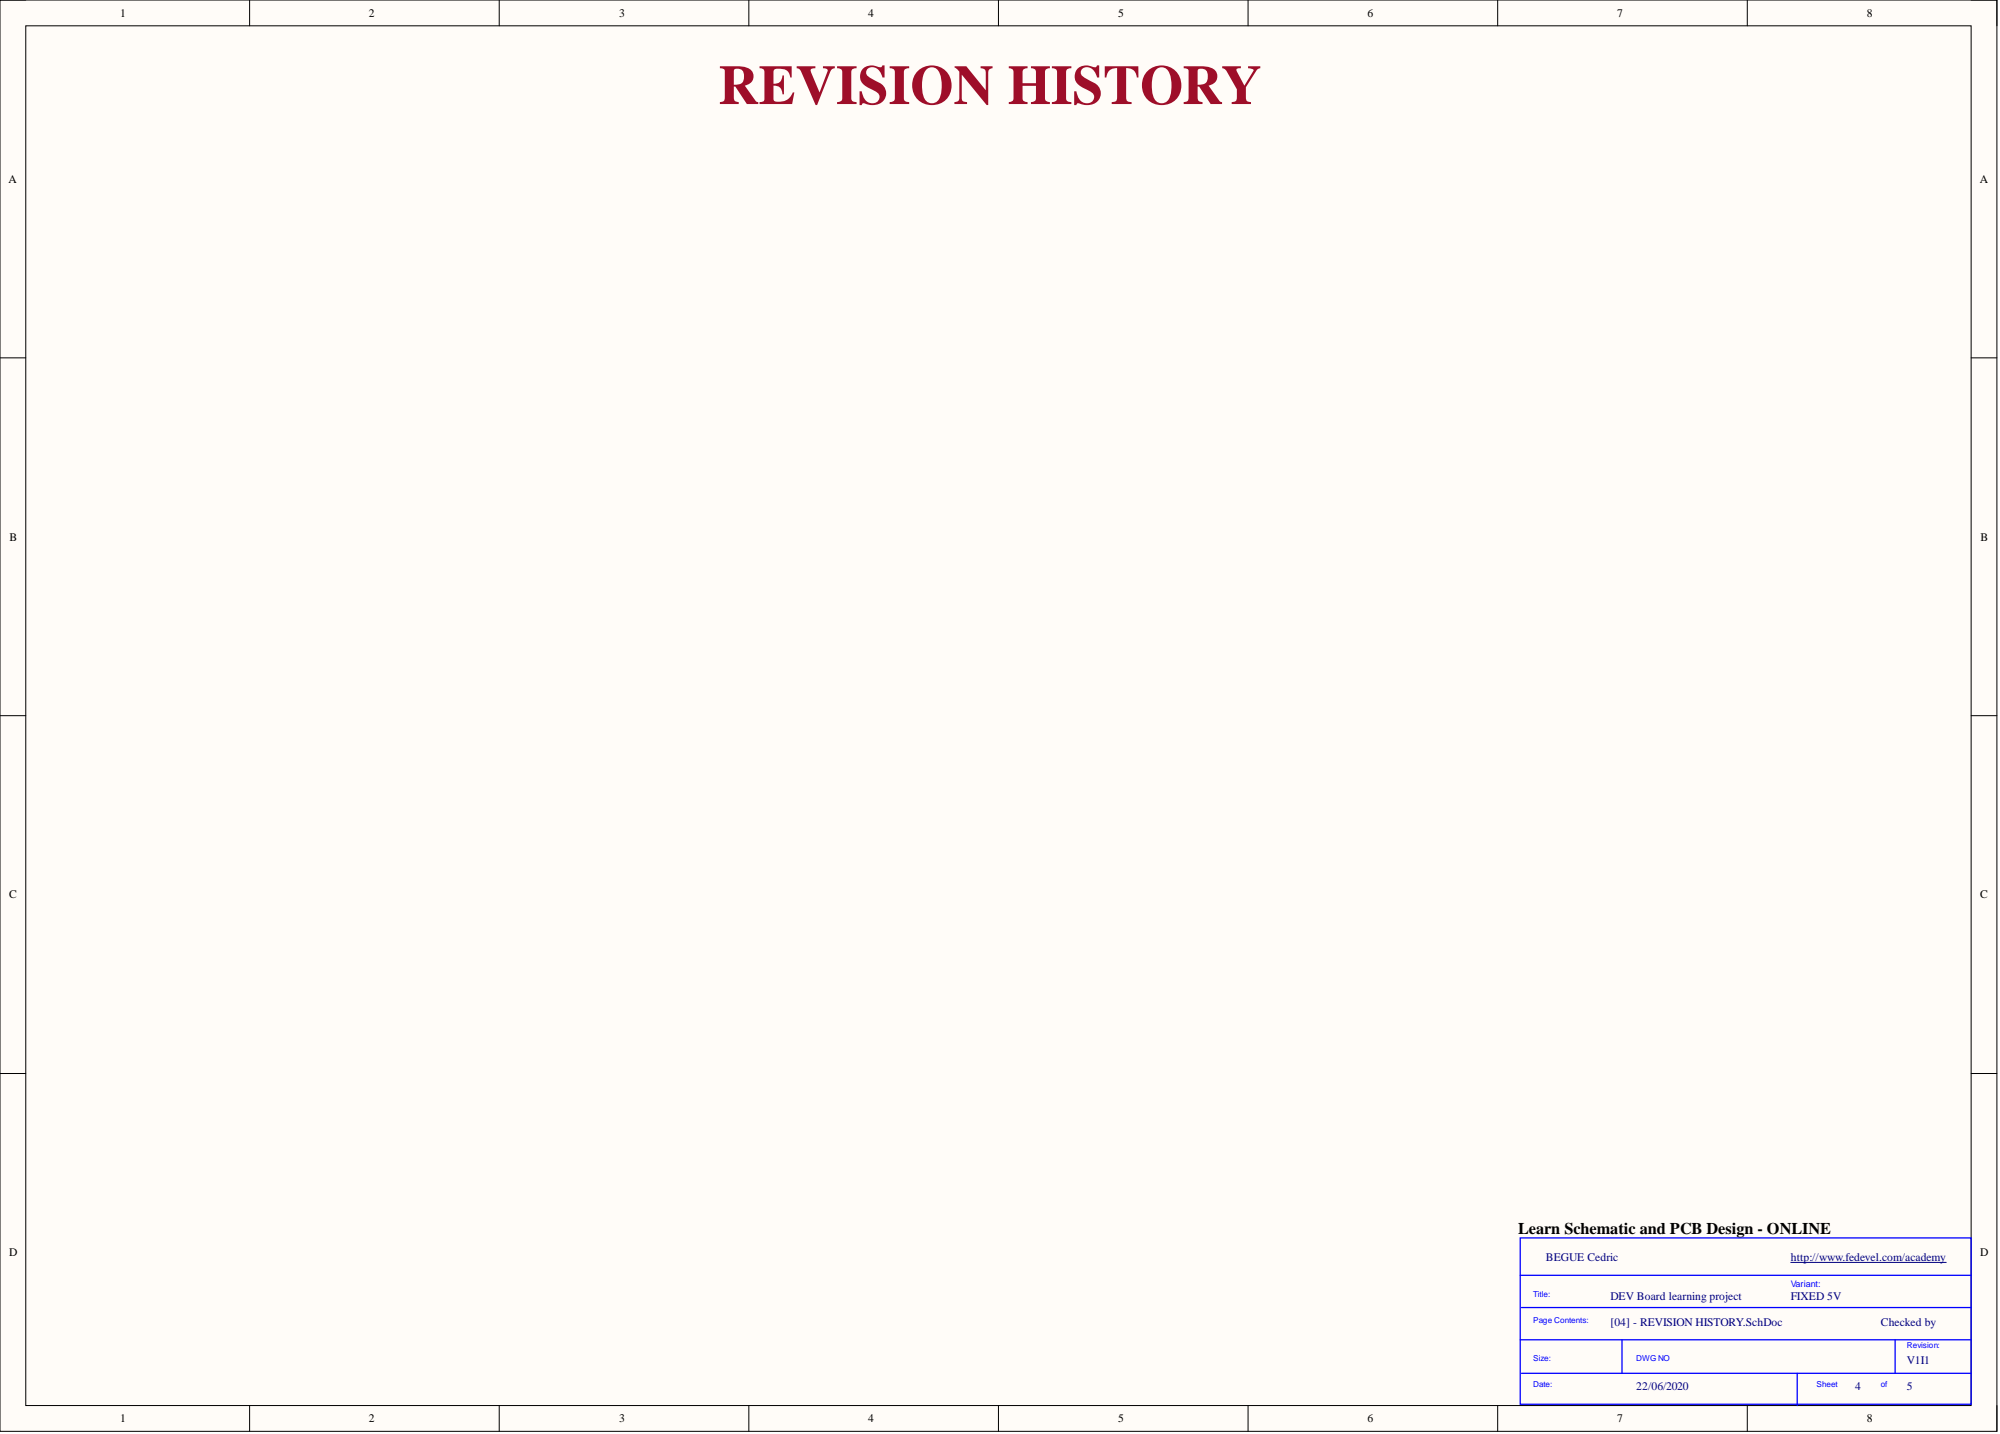
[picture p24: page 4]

Learn Schematic and PCB Design - ONLINE

http://www.fedevel.com/academy

DEV Board learning project

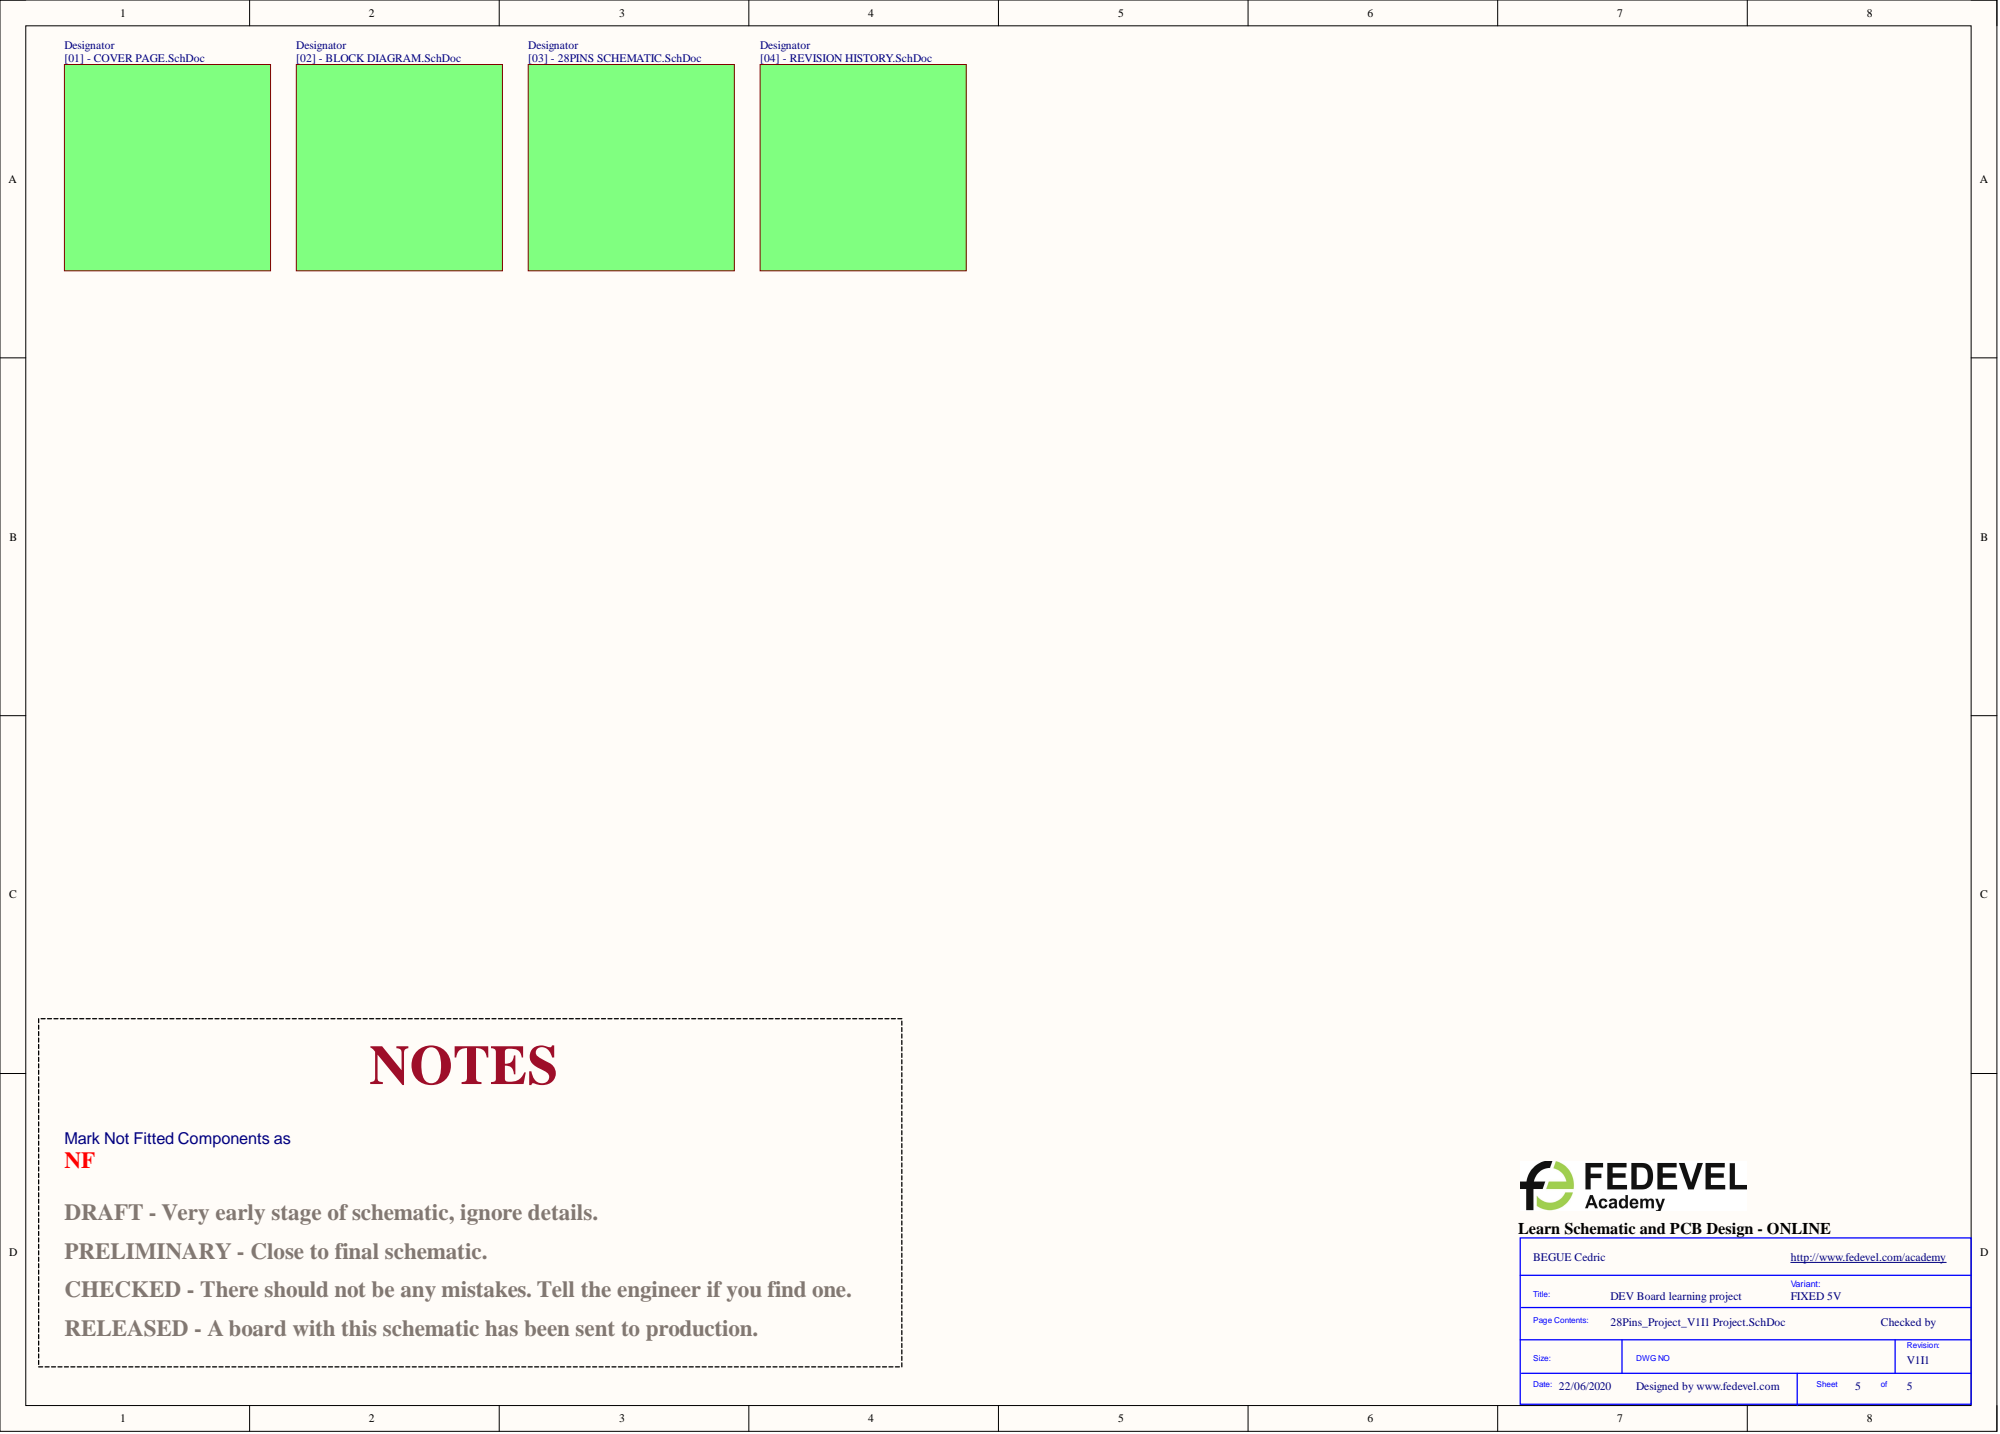
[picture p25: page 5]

Mark Not Fitted Components as

DRAFT - Very early stage of schematic, ignore details.
PRELIMINARY - Close to final schematic.
CHECKED - There should not be any mistakes. Tell the engineer if you find one.
RELEASED - A board with this schematic has been sent to production.

Learn Schematic and PCB Design - ONLINE

http://www.fedevel.com/academy

DEV Board learning project

Designed by www.fedevel.com

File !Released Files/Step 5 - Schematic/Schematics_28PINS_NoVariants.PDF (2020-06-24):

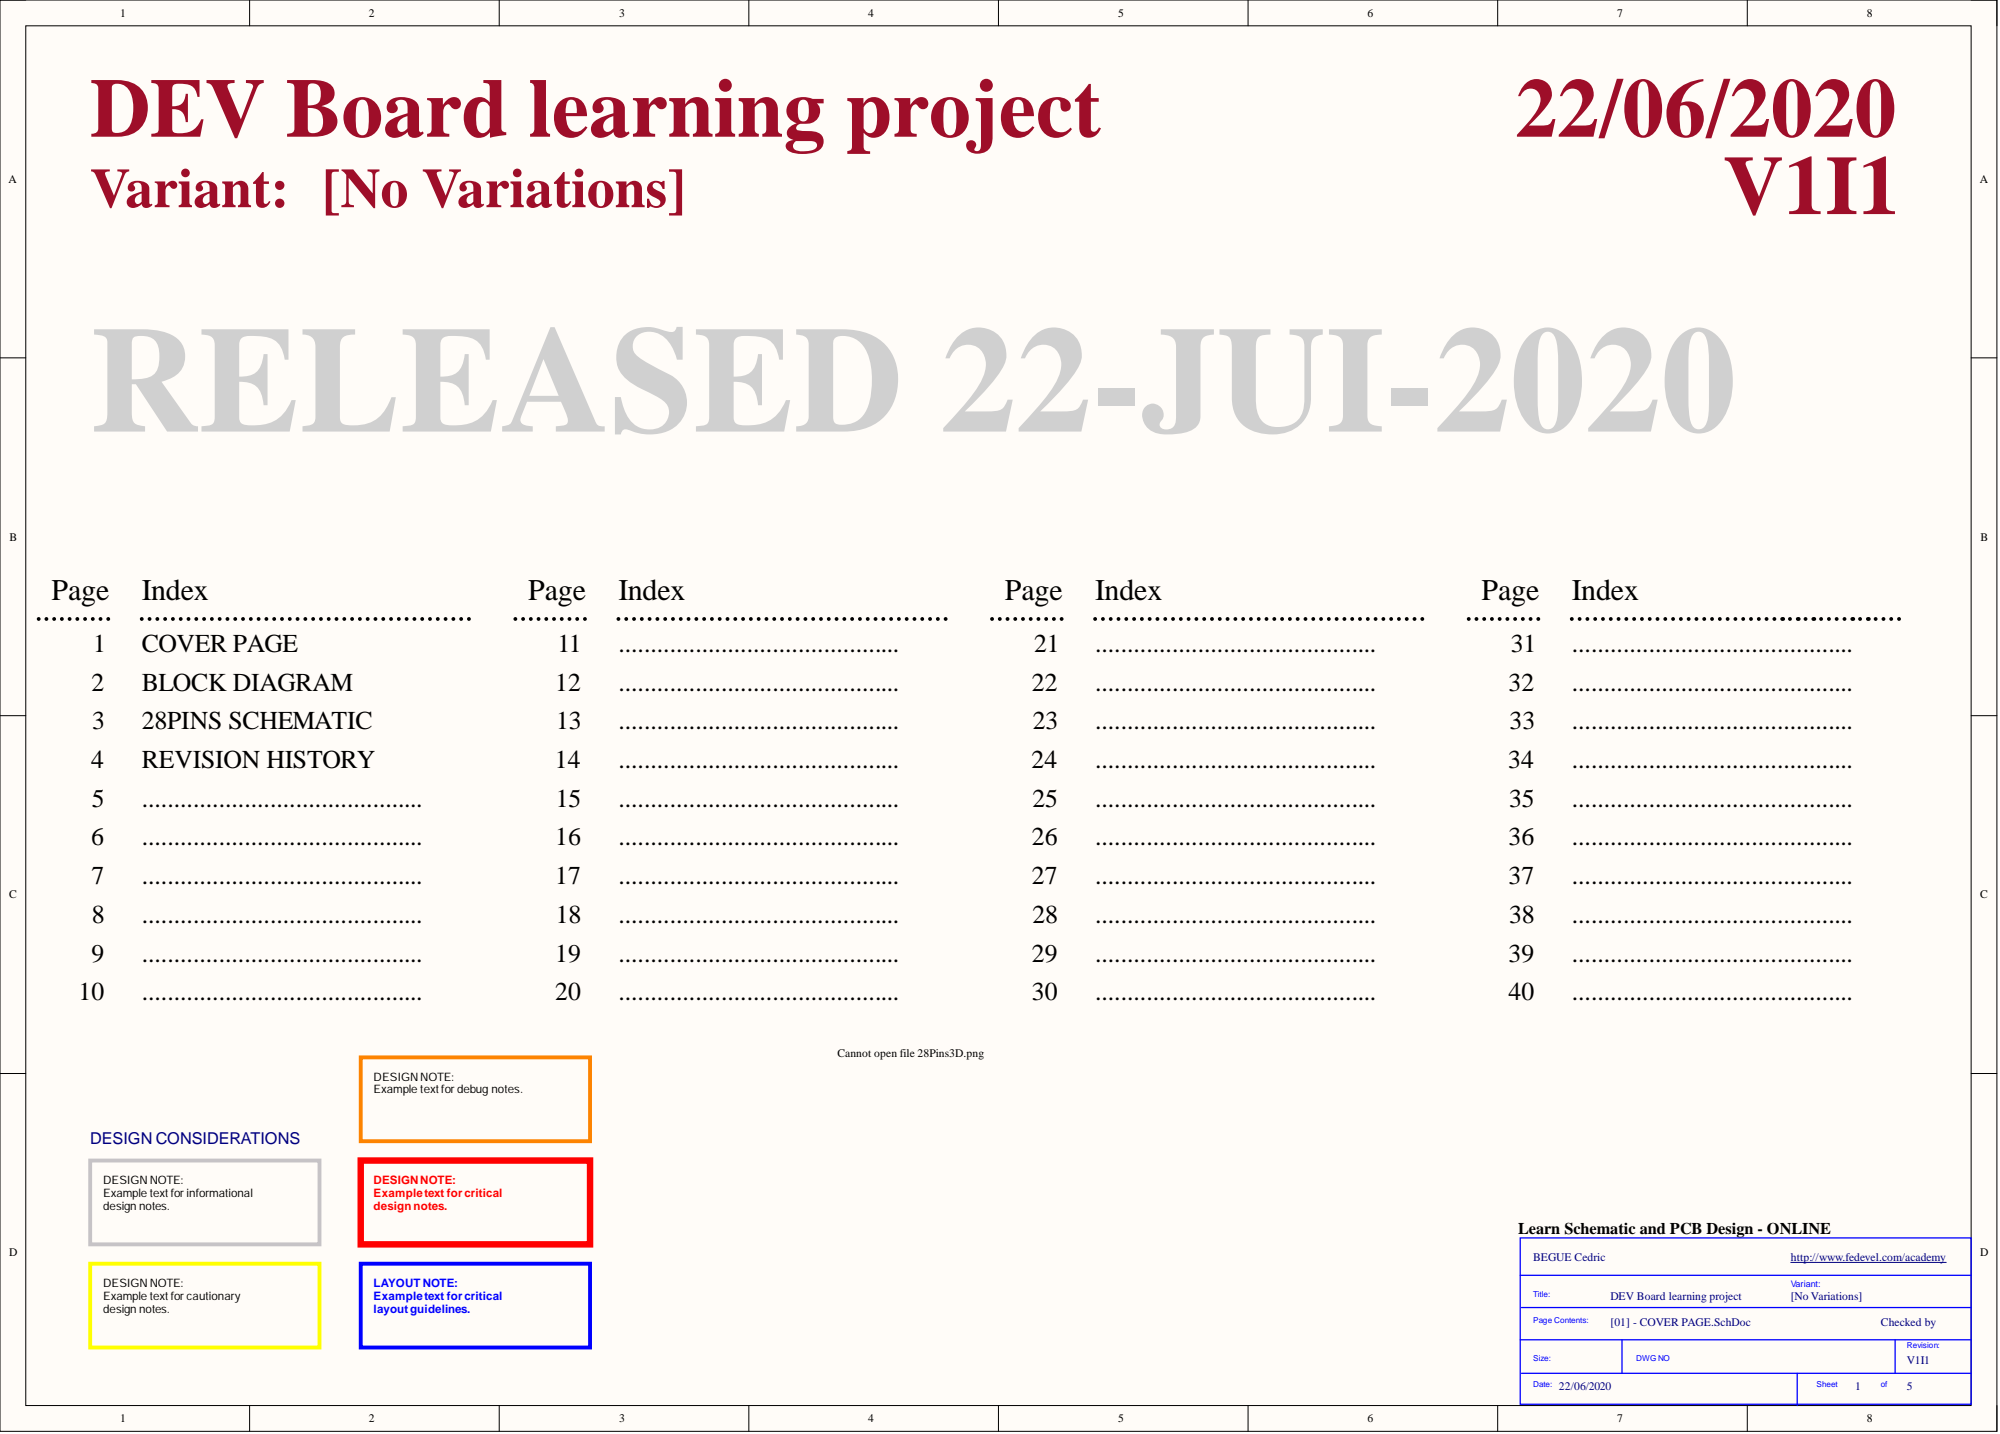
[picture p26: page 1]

Cannot open file 28Pins3D.png

DESIGN NOTE:
Example text for debug notes.

Example text for informational
design notes.

Example text for critical

Learn Schematic and PCB Design - ONLINE

http://www.fedevel.com/academy

Example text for cautionary

LAYOUT NOTE:
layout guidelines.

DEV Board learning project

Size: | DWG NO | Revision: V1I1

Date: | Sheet of

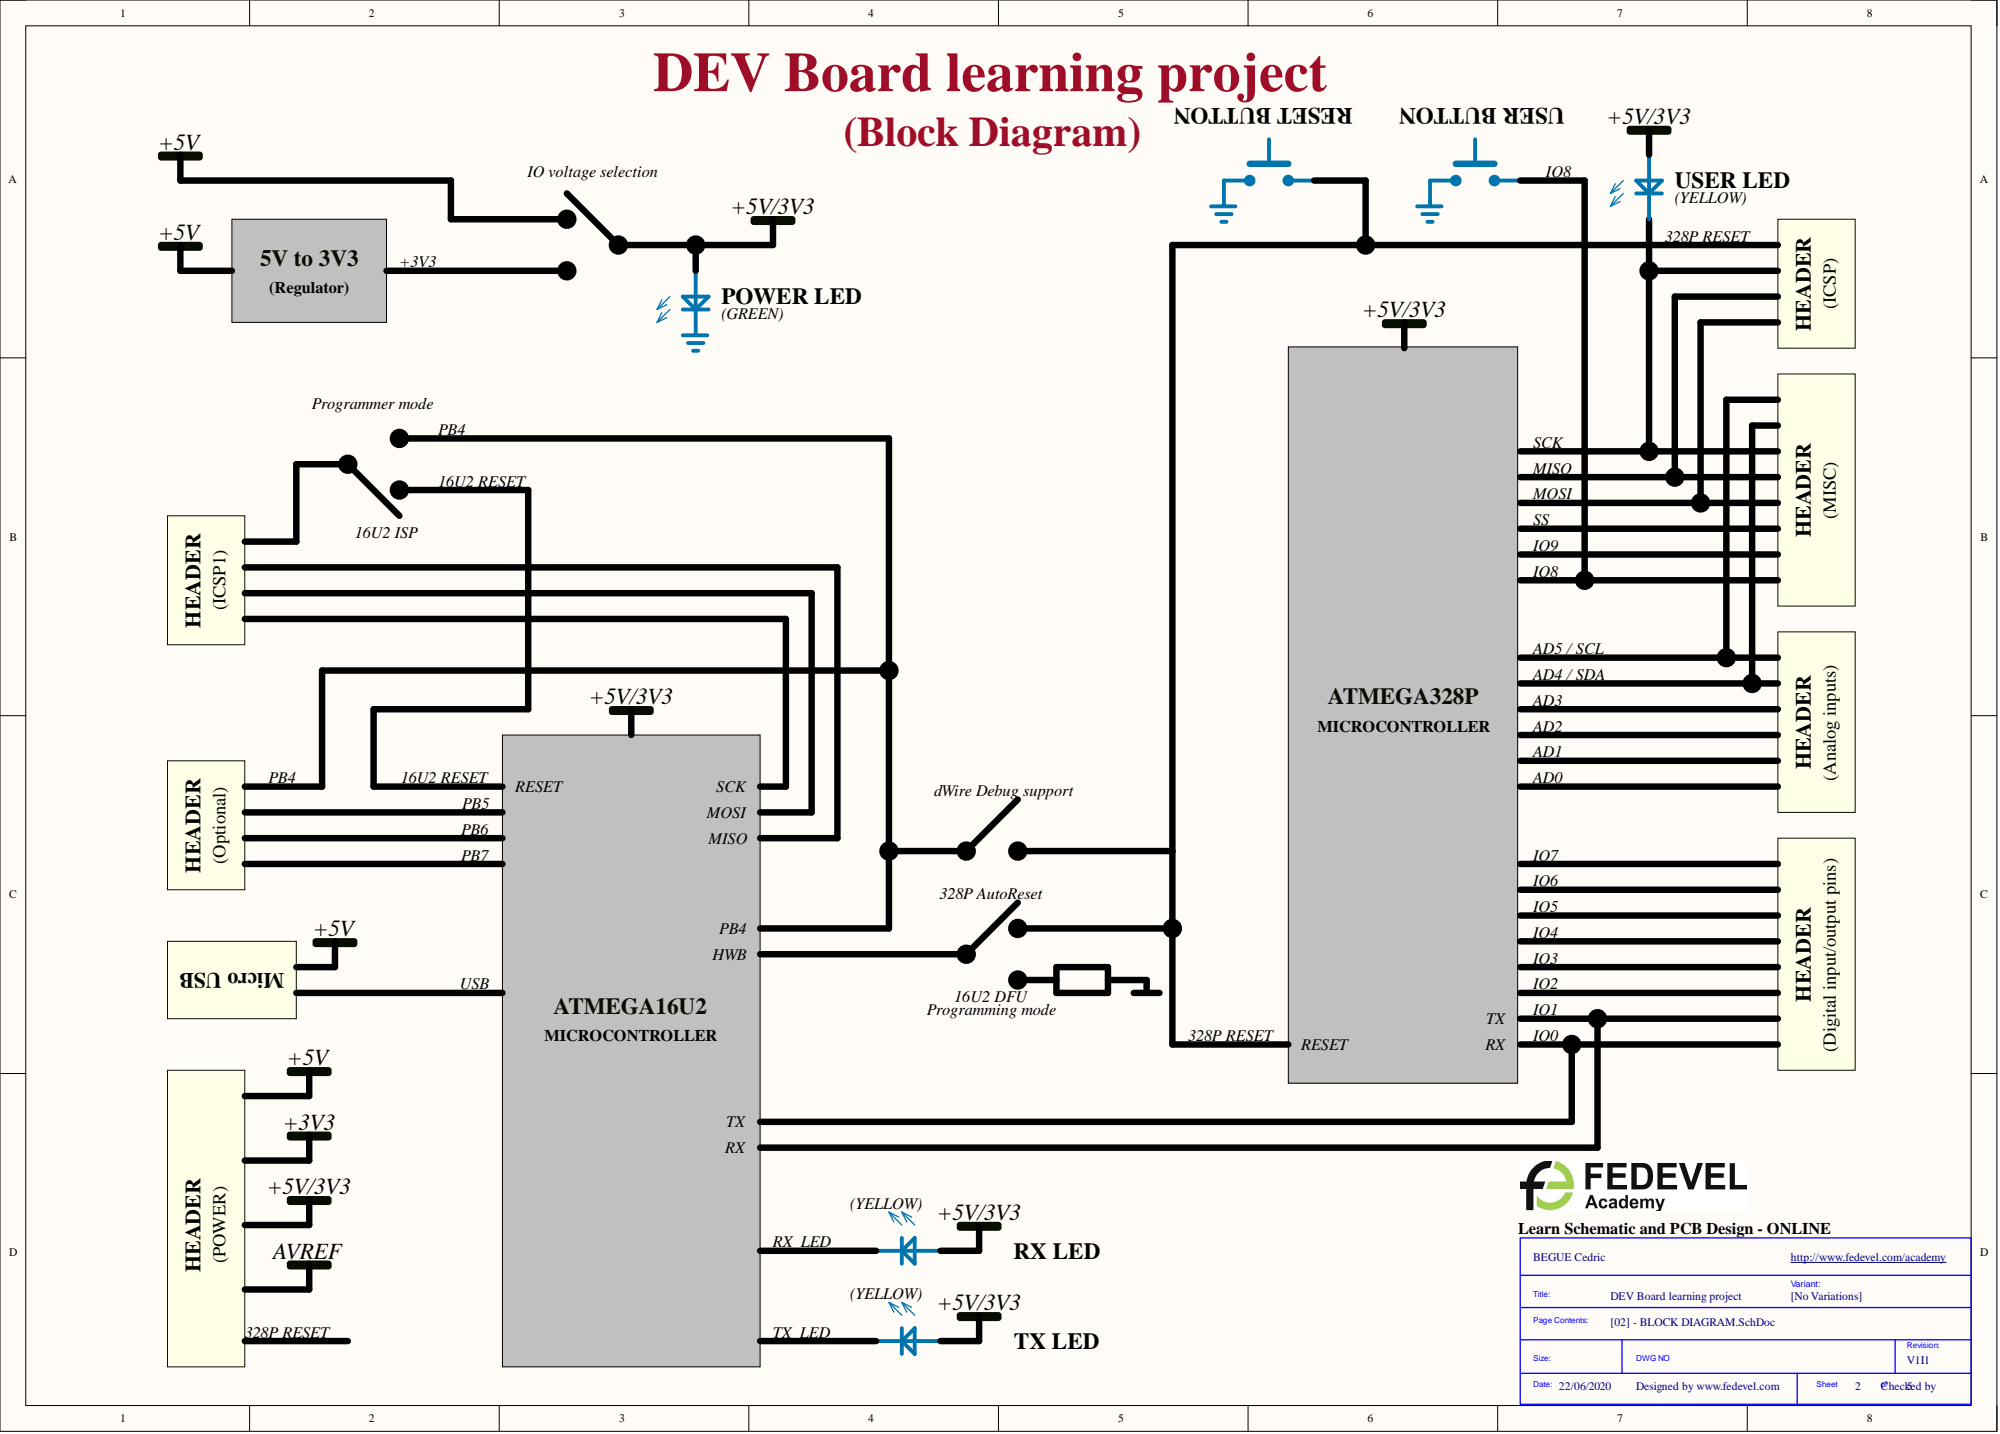
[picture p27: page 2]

DEV Board learning project

MISO
MOSI
SS
IO9
IO8

AD5 / SCL
AD4 / SDA

Learn Schematic and PCB Design - ONLINE

http://www.fedevel.com/academy


DESIGN NOTE:
This board supports 5V or 3V3 voltage level on the IO pins:
1) 5V IO - Fit everything as defined in this schematic. NF means, do not fit this component.

28PINS - SCHEMATIC
based on : http://www.28pins.com

2) 3.3V IO - Remove R27, Fit R28,*Replace Y1 (change from 16MHz to 10MHz), *Replace Y2
(change from 16MHz to 8MHz).

3) Both 5V and 3V3, selected through JP4 - Remove R27, Remove R28, Fit JP4,*Replace Y1
(change from 16MHz to 10MHz), *Replace Y2 (change from 16MHz to 8MHz).

*Note: The 16MHz crystals are not recommended for 3.3V operation. We need to adjust their
values, thats why the change.

IMPORTANT: Once you change the crystal value, you may need to re-compile your source code.

About JP3:
1) DebugWire support - Short 1&2. This was added to support possible debugWire debugging
(programming?) of 328P through 16U2. In this case, the 16U2 needs to have a correct firmware
and has to behave as a debugWire tool.

2) ISP programmer mode - Short 2&3. In this case, take a cable and connect J5 & J6 together.
Upload AVRISP MKII firmware into 16U2 and you can program 328P. Example of AVRISP MKII
firmware can be found at LUFA projects: http://www.fourwalledcubicle.com/LUFA.php (Tip:
remap LEDs of the default AVRISP MKII LUFA project to the RX and TX LEDs on the 28Pin
board)

3) ISP header - Short 3 & 4. In this mode, the ICSP1 header is used as a standard ISP header to
program 16U2 through ISP interaface by an ISP programmer.

UVCC 31 AVCC 32 | 16U2_PB6 | 1 1 2 4 NF | 2 3 3 4

16U2_MISO
16U2_MOSI

UCAP 27 | | 16U2PROG_328P_RESETn 16U2TX_LED | 16U2_SCLK

3 | CON_USB_P | C7

About JP1:
1) Autoreset Enabled - Short 1&2. In this case, 16U2 is used to reset 328P when firmware inside
328P is updated from Arduino IDE.

2) 16U2 DFU mode Enabled - Short 2&3. 16U2 HWB pin is sampled by 16U2 during RESET. If
pulled low, then after Reset the 16U2 will go into DFU mode (it's the mode when you can flash
16U2 firmware through USB and Atmel Flip software: http://www.atmel.com/tools/flip.aspx ).

DIP socket Power selection

This board can be powered from micro USB
connector (J7) or a single +3.3V power rail
(through J1 pin 4). If +3.3V is used, fit R26 and
R28. In this case, JP4 & R27 must NOT be
fitted, otherwise the board may be damaged.

To power the
board when not
using the usb port

AD5/SCL
AD4/SDA

Pin 8 (VIN) is not
supported

SCK R 22R | R13

AVCC 20 | | MISO

PC6/PCINT14/RESET 1 | | IO8

Mounting holes 7.4mm pad 3.2mm drill
BOARD MOUNTING HOLES
ONE IN EACH CORNER
Fiducials

PB7/PCINT7/TOSC2/XTAL2 10 | AD1

This LED is inverted:
- SCK High = LED
OFF
- SCK Low = LED ON

LAYOUT NOTE:
1) Route all the POWER tracks with minimum track width 0.4mm.
2) Route all the other tracks by 0.4mm and change them by the end of
the design to 0.2mm. To change all of them at once, use this filter
"(not InNet('+*') and not InNet('GND')) and IsTrack and (OnLayer('L1') or
OnLayer('L2'))" and then set 0.2mm width in PCB Inspector panel.

Learn Schematic and PCB Design - ONLINE

http://www.fedevel.com/academy

DEV Board learning project


Learn Schematic and PCB Design - ONLINE

http://www.fedevel.com/academy

DEV Board learning project


Mark Not Fitted Components as

DRAFT - Very early stage of schematic, ignore details.
PRELIMINARY - Close to final schematic.
CHECKED - There should not be any mistakes. Tell the engineer if you find one.
RELEASED - A board with this schematic has been sent to production.

Learn Schematic and PCB Design - ONLINE

http://www.fedevel.com/academy

DEV Board learning project

Designed by www.fedevel.com







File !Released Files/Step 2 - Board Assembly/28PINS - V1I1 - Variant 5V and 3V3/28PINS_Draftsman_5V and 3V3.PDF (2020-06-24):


View from Top side (Scale 1:1)

View from Bottom side (Scale 1:1)
